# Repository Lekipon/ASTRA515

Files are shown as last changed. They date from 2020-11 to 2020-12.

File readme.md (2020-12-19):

## *ASTRA 515 : A Symmetrical 5x15 Ortholinear Keyboard*

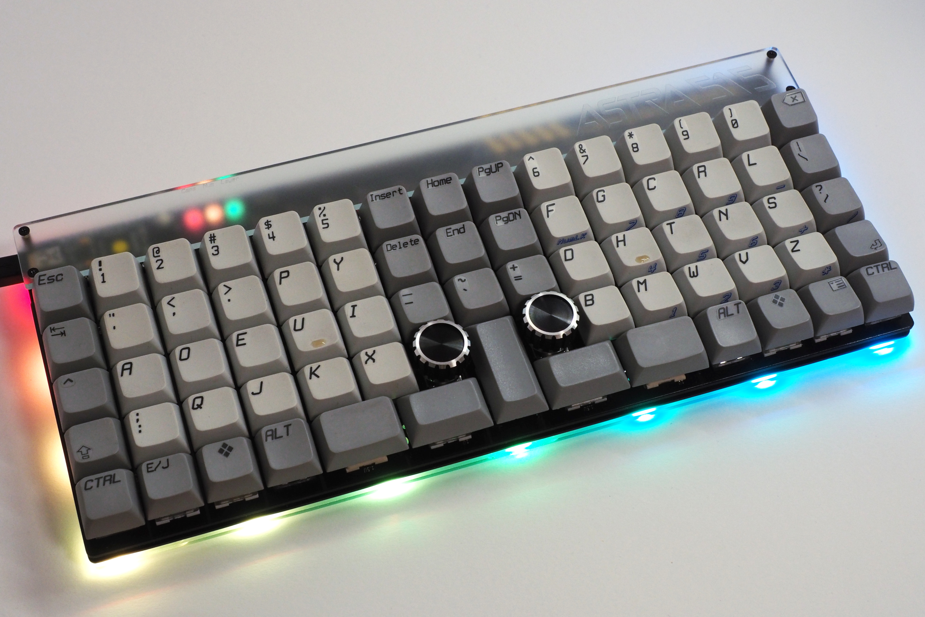
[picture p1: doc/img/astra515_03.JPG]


------

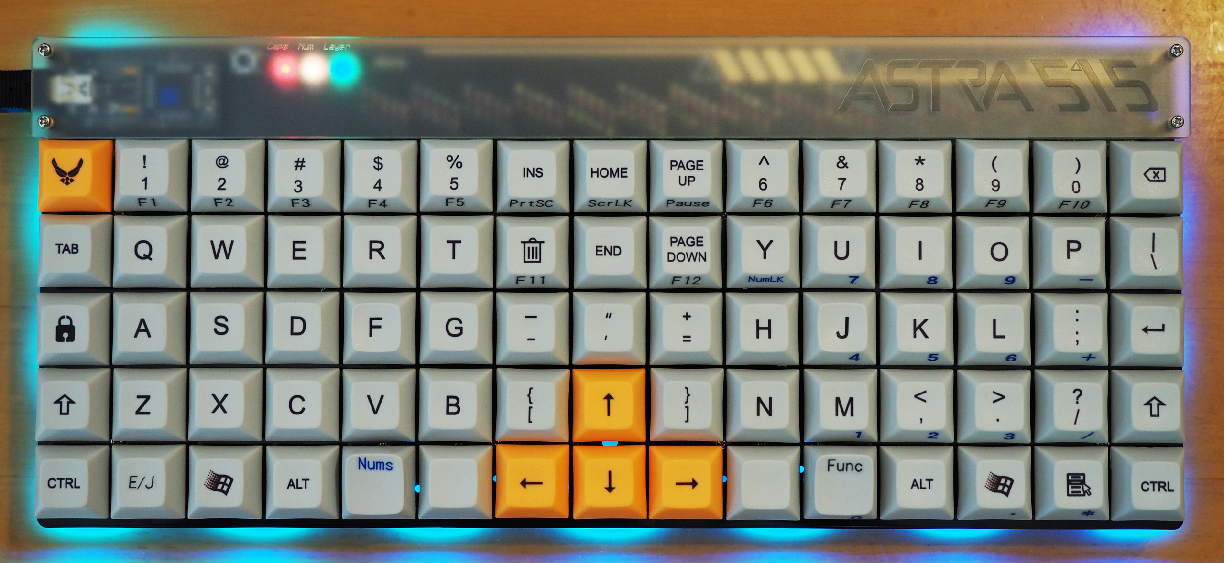
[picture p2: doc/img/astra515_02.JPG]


------

## **概要**

ASTRA 515は一体型の60％キーボードとほぼ同じサイズで5x15のオーソリニア（格子配列）となっている自作キーボードキットです。組立の難易度は決して高くないですが、キー数が多い故にハンダ付け箇所が多い点にご了承ください。

なお、ファームウェアは [QMK Firmware](https://github.com/qmk/qmk_firmware) を使用しています。

<br>

## 特徴

- ProMicro1個だけで可能な限り多くの実装をするためにDuplexMatrixの配線手法を利用。

- 左右の手のホームポジションの間隔を適度に離し、使用頻度の少ないキーを中央の区画に寄せた対称型オーソリニアレイアウト（全て1Uの構成にすれば片側寄せの非対称型のレイアウトも可能ですが...）。

- スイッチ付きロータリーエンコーダー（アルプスEC11/EC12互換）を2箇所に搭載可能。
- 好みに応じて親指周辺のキーを「1Ux3」または「1.5Ux2」の構成を選択可能（上の見本写真を参照）。また、中央下部のキーを縦の2U構成に変更することも可能（凸型配置の独立カーソルキーが不要な人向け、一般的には全て1Uの構成を推奨します）。

- RGBLED（WS2812B）による3連インジゲータの発光で「CapsLock」「NumLock」の状態を表示。また発光色によりレイヤーの状態を表示。

- RGBLEDのアンダーグロウに対応。なお、ハンダ付けの難易度がやや高いRGBLEDのみPCBに実装済。

- Kailhソケットにより大部分の区画がキースイッチの交換に対応（※中央下段の一部の区画を除く）。
- 標準添付のProMicroはUSBコネクタが「もげる」心配の無いMini-Bタイプを採用<br>（※別売となりますが普通のProMicroやElite-Cも使用出来ます）。

<br>

## キットに含まれている部品

1：PCB 1枚（RGBLEDを表面に3カ所、裏面に13カ所実装済）

2：スイッチマウントプレート

3：アクリルプレート3種（ボトムプレート用、トップカバー用、底上げ用、各1枚）

4：M2x8mmネジ（12本）

5：M2x5mmネジ（12本）

6：M2ワッシャー（8枚）

7：M2x12mmスタッドスペーサー（4本）

8：M2x4mmスペーサー（12本）

9：M2x3mmスペーサー（8本）

10：ゴム足（小3個、大3個）

11：Kailh PCBソケット（MX用・65個）

12：ダイオード（リードタイプ・75個）

13：ProMicro（Mini-Bタイプ・1個）および12ピンコンスルー（2本）

14：4ピンタクタイルスイッチ（リセットスイッチ用・1個）

<br>

## キットとは別に用意が必要な部品

- Cherry MX互換キースイッチ（73個）

- 1Uキーキャップ（73個）

- スイッチ付きロータリーエンコーダおよびツマミ（各2個）。なお、ロータリーエンコーダを使用しない場合はキースイッチと1Uキーキャップの必要数は各75個となります。

- USBケーブル（Mini-Bタイプ・1本）

<br>

## 必要な工具類

- ハンダごて（HAKKO FX600を推奨・別売コテ先はT18-C2かT18-D16がおすすめ）
- ハンダこて台
- 先が細いピンセット（ダイオードの足を曲げる際に必要）
- 普通のハンダ（スズ60％/鉛40％）およびハンダ吸い取り線
- フラックス（洗浄液もあるとなお良し）
- 精密ドライバーセット（100均のものでOK）
- マスキングテープ
- ニッパー
- プライヤー

<br>

## ビルドガイド

#### [**1：組立手順**](https://github.com/Lekipon/ASTRA515/blob/master/doc/buildguide.md)

#### [**2：デフォルトキーマップとQMKファームウェアについて**](https://github.com/Lekipon/ASTRA515/blob/master/doc/firmware.md)

#### [**3：ProMicroの換装について・他**](https://github.com/Lekipon/ASTRA515/blob/master/doc/promicro.md)

#### [**４：ロータリーエンコーダの選定について（沼）**](https://github.com/Lekipon/ASTRA515/blob/master/doc/re_numa.md)

<br>

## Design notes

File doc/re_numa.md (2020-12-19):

## ロータリーエンコーダの選定について（沼）

- ASTRA 515では当初からロータリーエンコーダを2カ所に搭載するように設計していますが、必ずしも付けなければならないという訳ではありません。最初は全てMX互換スイッチを実装して5x15Ortho配列のキーボードとして使い、配列に慣れてからロータリーエンコーダに換装するというのも有りだと思います。

- 作者自身は仕事で[XD75re](https://kprepublic.com/collections/xd75/products/xd75re-xd75am-xd75-xiudi-60-custom-keyboard-pcb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)を使用していて、そこから出てきた不満点を洗い出した上でASTRA515を設計したという経緯があるので、最初からロータリーエンコーダを付けていますが、５ピンのロータリーエンコーダは一度ハンダ付けすると外すのにコツが必要なので、初めての人はすぐに実装しない方がいいかも知れないとも考えてます（今更ながらですいません・・・）。

- ということで、ロータリーエンコーダをいくつか試してみて検証しましたので、以下にレビューを記載させていただきます。他の自作キーボードキットでロータリーエンコーダを使用する場合にも参考になるかと思います。

  <br>

**1）遊舎工房さんで取り扱っている[ロータリーエンコーダ＆ノブセット](https://yushakobo.jp/shop/pec12r-4222f-s0024/)**<br>

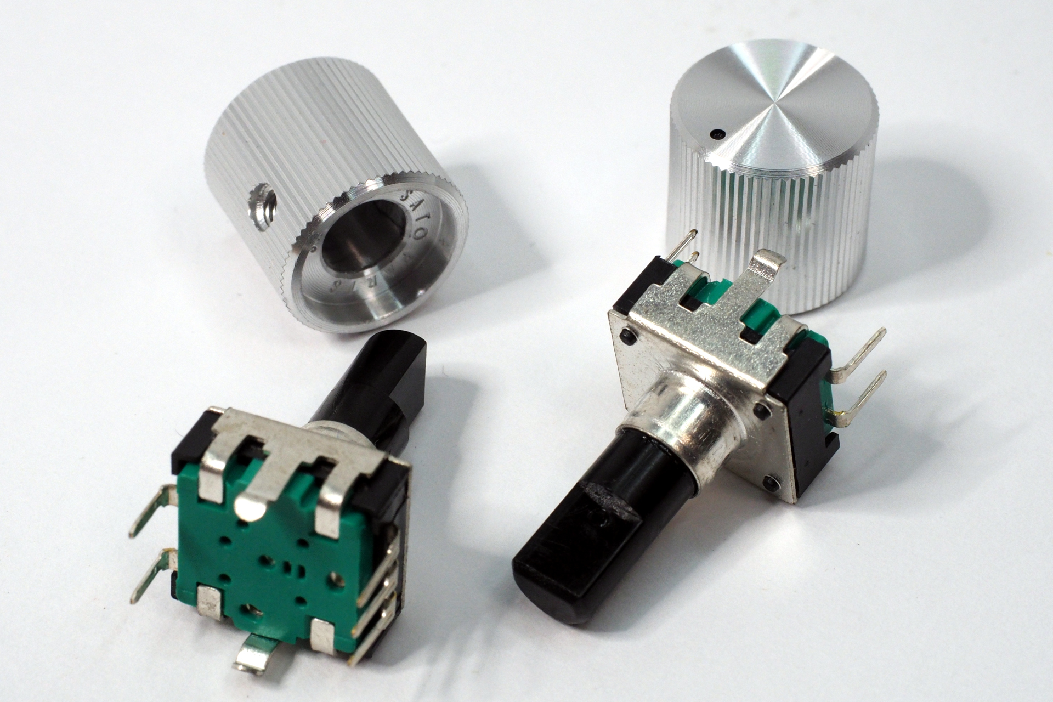
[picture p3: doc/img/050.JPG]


・Bourns社製の「PEC12R-4222F-S0024」とサトーパーツ社製の「K-29-6.1」アルミ削り出しノブのセットとなります。ノブだけでも単品で買うと350円とかする代物なので、なかなかのお買い得セットともいえます。

・PCB面からシャフト先端までの全高は22.5mmで、自作キーボードでの使用を考慮してやや短めのシャフトのとなっています。

・セットのノブは非常にシンプルな形状ながらも良好なグリップ感・・・特に側面と天面のエッジ部分の摩擦力が適正で、非常に実用的な選択だと思います。

・このセットではロータリーエンコーダが24パルス/24クリックのため、QMKファームウェアの「#define ENCODER_RESOLUTION」の値はデフォルト値の「4」の設定で使用します。

・実際に使った使用感ですが、プラスチックのシャフトながらも回した時の金属的なクリック感がなかなか心地よい感触です。あまりハードな使い方をしない前提なら、これで十分ではないかと思います。

・ただ、欲とは深いもので「親指一本でコロコロ回したいな～」とか「丈夫な金属シャフトのものを使いたい」といった欲が出てくると、以下のようにロータリーエンコーダ沼になってくるので十分に注意してください。

#### **2）アルプス EC11E18244A5**<br>

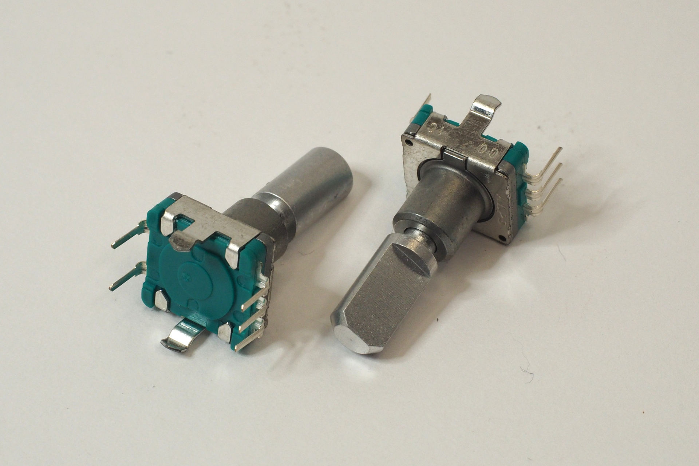
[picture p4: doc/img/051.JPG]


・PCB面からシャフト先端までの全高は24.5mm。プッシュスイッチは1.5mmと長いストロークで、柔らかいタッチが特長です。モノタロウやRSコンポーネンツで一個600円前後で売っています。

・18パルス/36クリックのため、QMKファームウェアの「#define ENCODER_RESOLUTION」の値は「2」の設定となります。具体的にはキーマップフォルダ内のconfig.hに当該セクションがありますので、設定値を「2」にしてファームウェアをビルドして使用します。

・EC11Eシリーズはこれがもっともシャフトが短い製品となりますので、このままでは自作キーボードで使用するには長すぎるという問題があります。ということで・・・<br>

#### **EC11Eのシャフトを斬る！**<br>

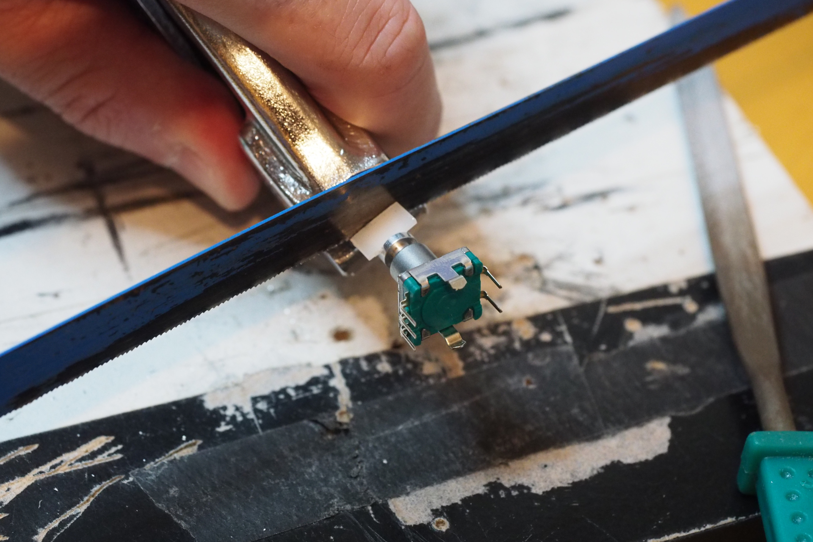
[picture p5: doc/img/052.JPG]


・金鋸を使用する際にはロータリーエンコーダの駆動部にダメージを与えないようにするために、必ずシャフト先端側をクランプしてカットします。

<br>

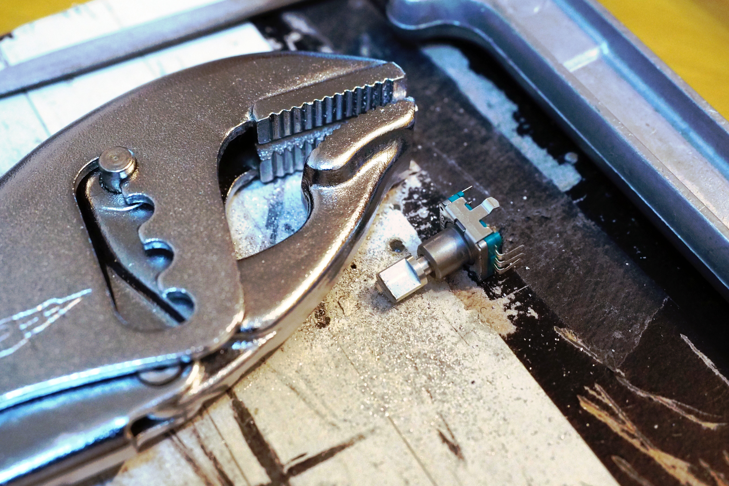
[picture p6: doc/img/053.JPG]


・5mmほどカットすれば、全高は約20mm弱。カット後はシャフトの先端のエッジ部分をヤスリで軽く面取りして仕上げます。自作キーボードでキーと隣接している状態ではこれくらいの低さが丁度いいくらいです。

・余談ですが、写真の工具は[スーパーツール社製のSG225](https://www.supertool.co.jp/products/products.php?eid=00084)。いわゆるバイスグリップ系の工具では世界的にも珍しい開口幅切り替え式が特長です。このシリーズの工具は個人的に何かと出番が多くて長年使っています。現在ではAmazonで2,200円で買えるので、一本持っておいても損はないと思います。

<br>

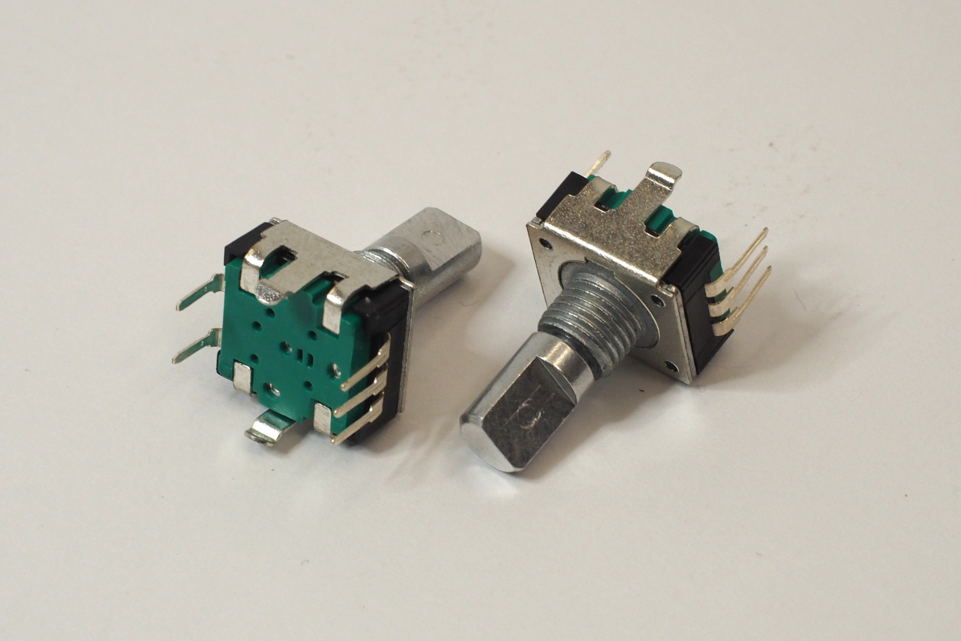
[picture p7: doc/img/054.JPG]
#### **3）Bourns PEC11R-4015F-S0024**<br>

・PCB面からシャフト先端までの全高は21.5mm（シャフト長が15mmでベース部分の高さが6.5mm）。プッシュスイッチは樹脂シャフトのPEC12Rシリーズ同様に0.5mmストロークの堅いタッチです。マルツオンライン等で一個250円前後で売っています。

・実は24パルス/24クリックの「PEC11R-4215F-S0024」と間違えてノンクリックの物を買ってしまい、これは失敗したなと思ったのですが・・・回転がとても軽くスムーズで指一本で簡単に回せるので逆に好都合でした。

・24パルス/ノンクリックのため、QMKファームウェアの「#define ENCODER_RESOLUTION」の値はクリック数を気にせずに自由に設定出来ます。例えば「2」に設定すると1回転で48回、「3」に設定すると1回転で32回、「4」に設定すると1回転で24回、といった出力回数となります。

・金属シャフトのPEC11Rシリーズではこれがもっともシャフトが短い製品となりますので、キーキャップの低さやノブの高さによっては、アルプスEC11E同様にシャフトを若干カットする必要が出てきます。<br>

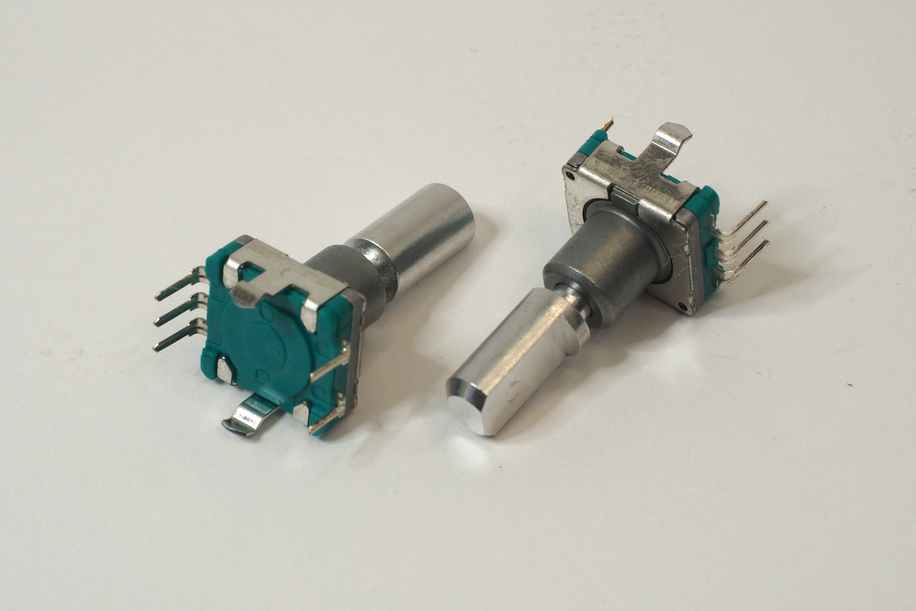
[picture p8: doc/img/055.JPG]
#### **4）アルプス EC11E1834403**<br>

・先に紹介した「EC11E18244A5」のノンクリック版。これもプッシュスイッチは1.5mmと長いストロークで、柔らかいタッチです。モノタロウやRSコンポーネンツで一個600円前後で売っています。

・18パルス/ノンクリックのため、QMKファームウェアの「#define ENCODER_RESOLUTION」の値はクリック数を気にせずに自由に設定出来ます。例えば「2」に設定すると1回転で36回、「3」に設定すると1回転で24回、「4」に設定すると1回転で18回、といった出力回数となります。

・こちらはノンクリックとはいえ、残念ながら中のグリスが堅いのか回転がかなり重いです。ただ、使い込むうちに次第に軽くなってくる傾向があるので。今後使い込んで馴染ませてみたいと思います。

<br>

## ノブの選択について（更なる沼）

- 上記でロータリーエンコーダについて数点のレビューをしましたが、ノブに関してはネジ止めで簡単に交換できる代わりに「実際に付けてみないと分からない」という要素がかなり発生します。奮発して買った高価なアルミ削り出しノブがイマイチで、安価な樹脂製ノブの方が良かったなんてことは茶飯事です。

- 一般に15mm径のノブなら周辺のキーの打鍵を妨げることはありませんが、18～19mm径クラスの大径ノブを使用すると隣接するキーが打ちづらくなるため、より低く装着する必要が出てきます。

- 現時点で下の写真のノブを試していますが、今後も徐々に増えていく可能性は十分あります。

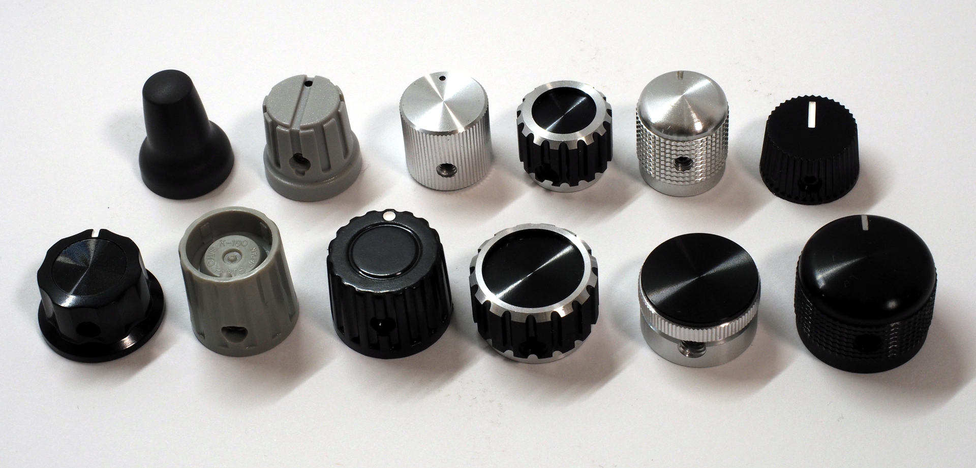
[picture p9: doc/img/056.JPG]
  

  <br>

  ・ここでは、実際に試したもののうち、いくつか写真付きでレビューしたいと思います。なお、ASTRA515に装着した見本写真では、PEC11R-4015F-S0024（全高21.5mm）とMX互換スイッチ、DSAキーキャップの組み合わせとなっています。

<br>

#### **1）サトーパーツ K-29-6.1**<br>

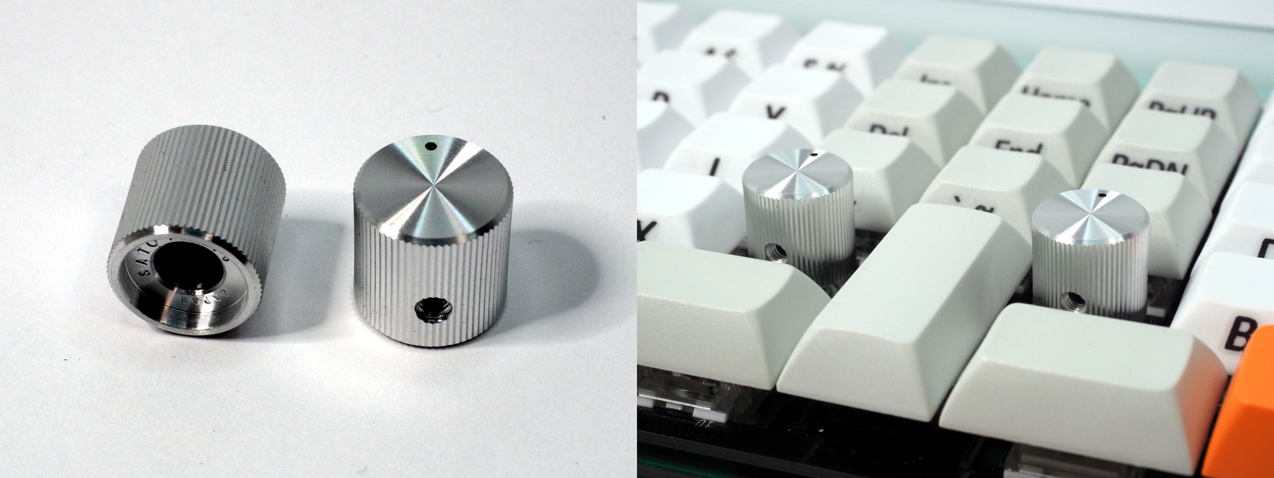
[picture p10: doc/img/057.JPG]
<br>

・詳細は[こちら](http://www.satoparts.co.jp/JPN/item/K/K-29-6.1/)。遊舎工房さんのロータリーエンコーダセットの添付品でもあります。

・見た目的な面白みはありませんが、エッジ部分の摩擦力が適正なため、指一本での回転操作にもある程度対応できます。

#### <br>**2）Linkman CP-CE15-5-S(6.1)W6**<br>

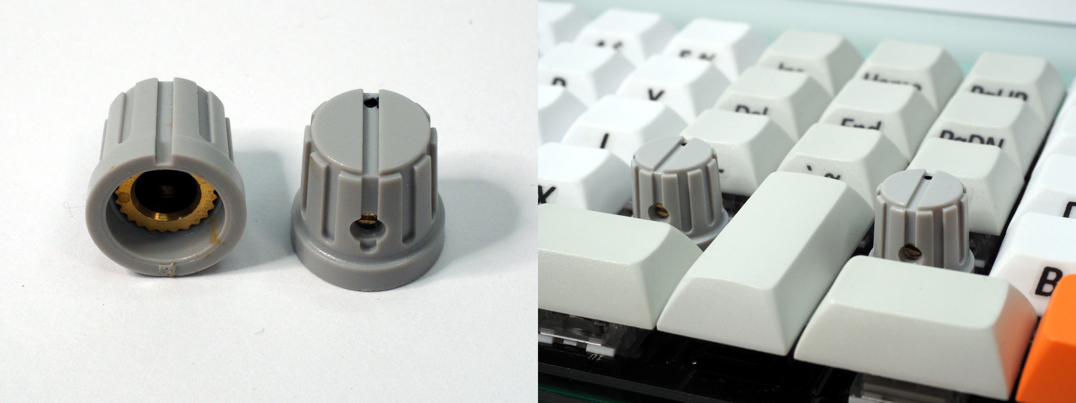
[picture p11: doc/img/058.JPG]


・詳細は[こちら](https://www.marutsu.co.jp/pc/i/837992/)。秋葉原の電子部品ショップでよく扱っている安価なノブです。グレーの他に黒色もあります。

・これも、エッジ部分の摩擦力が適正なところが良いと思います。また、グレー系のキーキャップに近い色で外観的にしっくりくるという良さもあります。

・取り付けの穴が結構深くて、プッシュスイッチと干渉しやすいので、あまり低く取り付けられないという欠点はあります。

<br>

#### **3）サトーパーツ K-4071**<br>

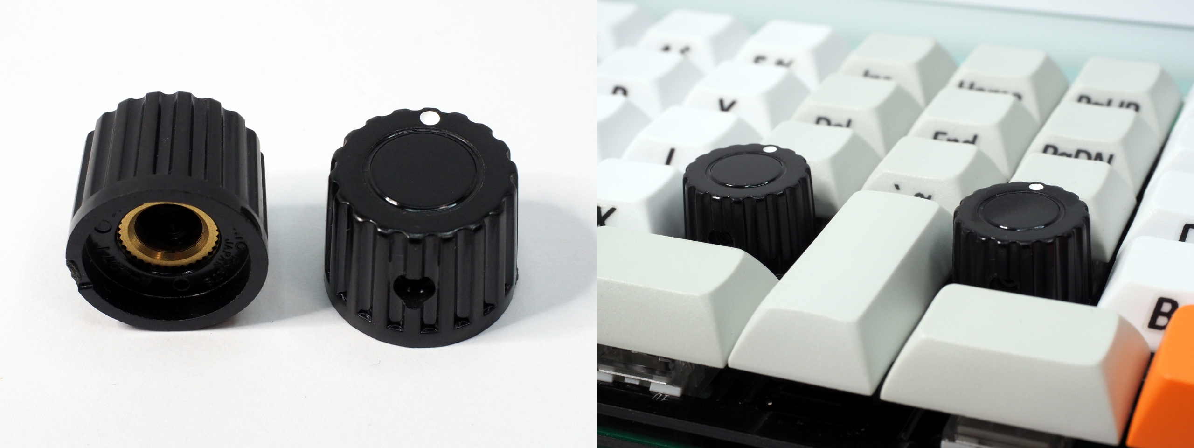
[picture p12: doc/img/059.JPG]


・詳細は[こちら](http://www.satoparts.co.jp/JPN/item/K/K-4071/)。マルツオンライン等で扱っています。

・大径でかつエッジ部分の摩擦力が適正、低く取り付け出来るためDSAのキーキャップとの相性も良いです。ただし、見た目が安っぽいのが一番の難点で色も黒しか有りません。実用性最優先の選択となります。

<br>

#### **4）サトーパーツ K-52-KE-3**<br>

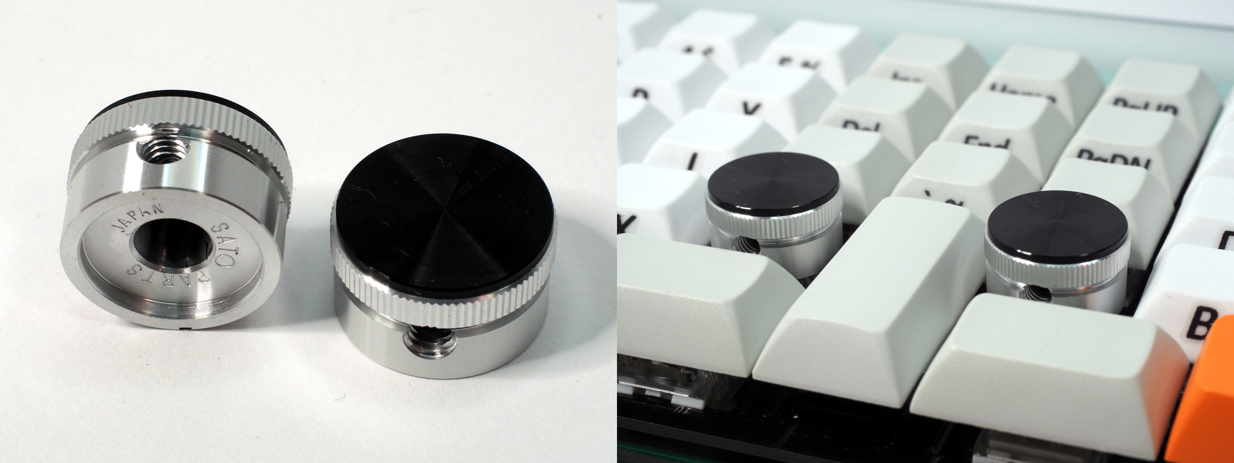
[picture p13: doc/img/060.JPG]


・詳細は[こちら](http://www.satoparts.co.jp/JPN/item/K/K-52-KE-3/)。マルツオンライン等で扱っています。

・大径ですが、エッジ部分の摩擦力があまり強くないです、低く取り付け出来ることと、外観が安っぽくないというのが良い点だと思います。

<br>

#### **5）サトーパーツ K-38（中）**<br>

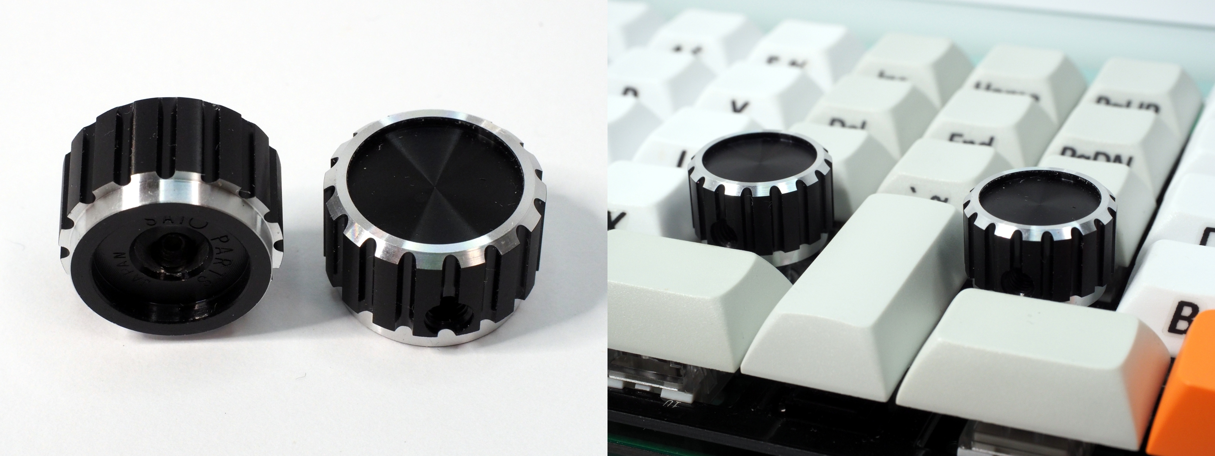
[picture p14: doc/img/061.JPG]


・詳細は[こちら](http://www.satoparts.co.jp/JPN/item/K/K-38/)。マルツオンライン等で扱っています。

・中サイズだと直径19mmでMXのキーピッチとマッチします。エッジ部分の摩擦力という点では最強ともいえます。ただし、断面図を見ての通り穴が浅いため低く取り付け出来ないという欠点があります。これはSAやMDAのような背の高いキーキャップと組み合わせて使うべきかと思います。

・削り出しのエッジが鋭いため、日々のエタノール消毒で肌荒れした指先には少々辛いという問題もあります。

<br>

<br>

（以上、必要に応じて随時書き足すかも）

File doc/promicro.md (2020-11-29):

# ProMicroの換装について

- ASTRA 515では一般的な自作キーボードキットと違い、標準添付のProMicroはやや大ぶりなMini-Bタイプのものとさせていただいています。理由は以下の通りとなります。
  - 基板のレイアウトが大柄な故にProMicroの設置場所に余裕があった。
  - HHKB等の市販キーボードでケーブル脱着式のキーボードでは、長年の間Mini-Bコネクタが標準だった（現在の市販キーボードではMini-BからType-Cコネクタに移行する過渡期）。
  - 通常のProMicroではMicroUSBコネクタが「もげる」問題に根本的な対策がされていない。
  - Mini-BタイプのProMicroも調達コストは通常のProMicroとほぼ同じ。<br><br>
- 上記の事情でMini-Bタイプを採用していますが、一般的な[ProMicro](https://yushakobo.jp/shop/promicro-spring-pinheader/)や[Elite-C](https://yushakobo.jp/shop/elite-c/)も使用可能なように設計してあります。MicroUSBコネクタは「もげる」問題があるので、換装の際はElite-Cを推奨しますが、MicroUSBケーブルを使いたい事情がある場合は、ProMicroのUSBコネクタをエポキシ接着剤等で補強して使用してください。
- なお、遊舎工房さんで取り扱っているProMicro（コンスルー付きで1,100円）について、少しだけ朗報があります。詳細は以下の比較写真をご覧いただければ分かりますが、USBコネクタがの実装が強化されています。

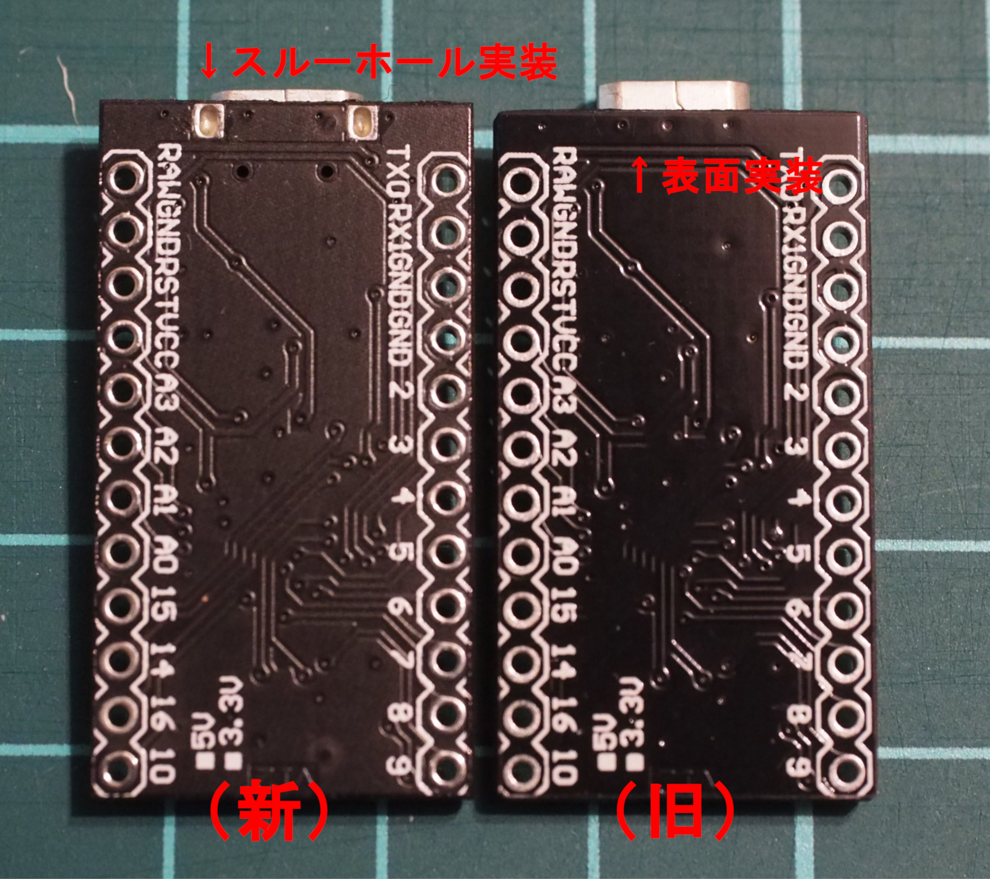
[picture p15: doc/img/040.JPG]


・USBコネクタの実装が表面実装からスルーホール実装に変更されています。また、基板の表面仕上げが艶ありから艶消しになっています。

<br>

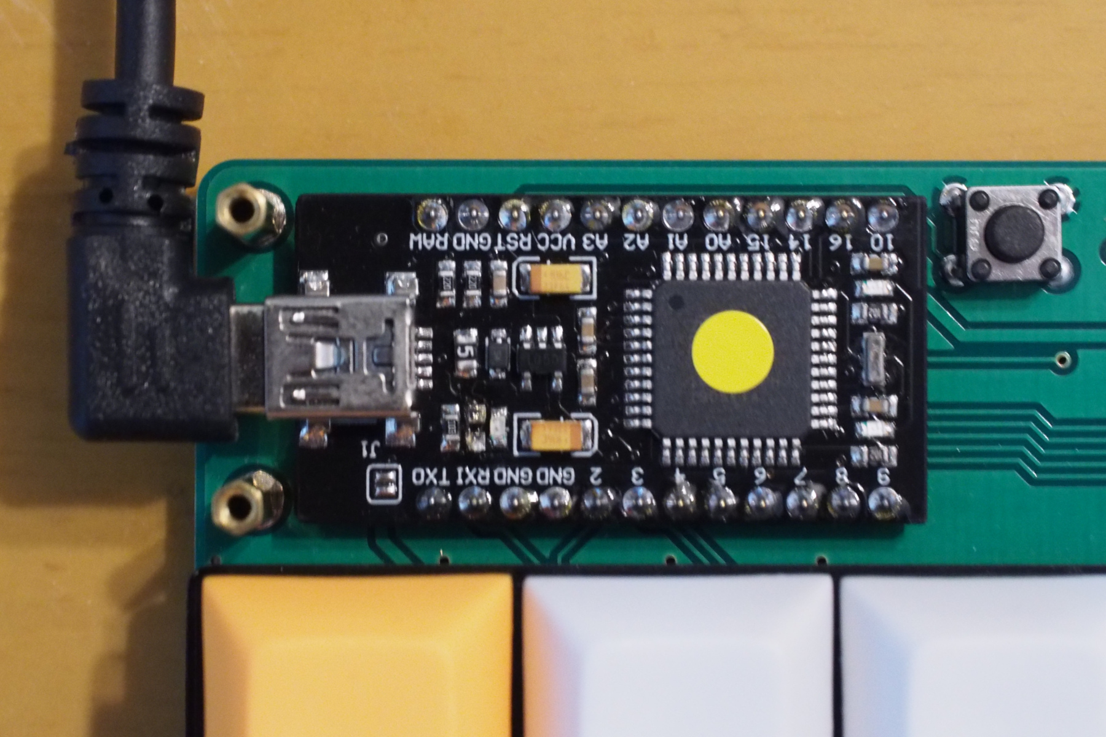
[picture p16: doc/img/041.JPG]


・スルーホール化されたとはいえ2カ所止めのままでは不安が残るので、結局は写真のようにエポキシ接着剤でコネクタ周辺を補強して使うことになります。強化されたこと自体よりも、補強の際に接着剤がコネクタ内部に流入しにくくなったというメリットの方が大きいかも知れません。

<br>

- 下の写真は標準添付のProMicroを取り付けた状態となります。

  

<br>

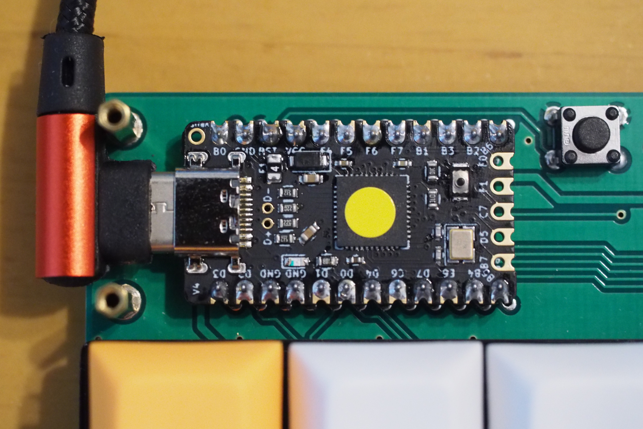
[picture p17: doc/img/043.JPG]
- これをElite-Cに換装した場合は以下の写真のようになります。

  ・ProMicroとの大きさの違いにより、Type-Cコネクタが奥まった位置になる点にご注意ください。

<br>

- この状態でL型のType-Cケーブルを使う場合は下の写真のように、コネクタの突き出し量が12mm以上あるものを使用してください。

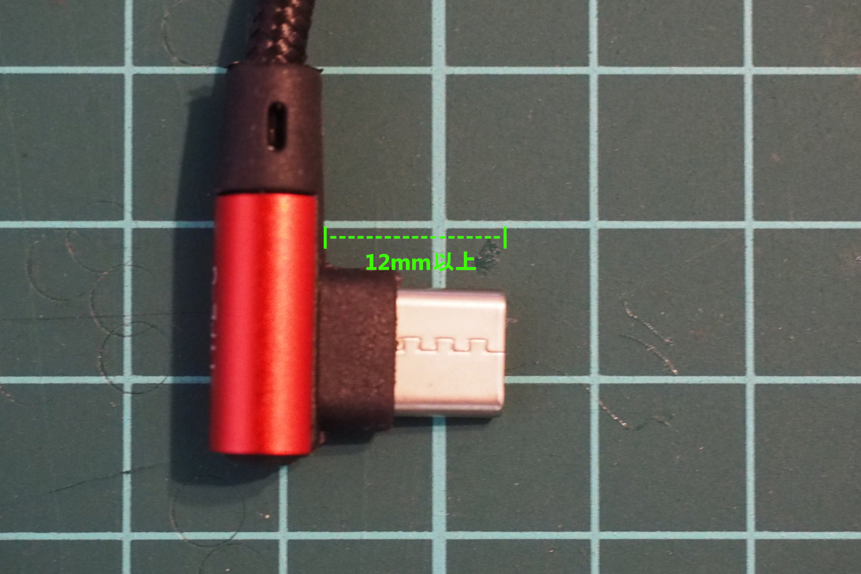
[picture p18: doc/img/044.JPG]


・余談ですが、写真のケーブルはダイソーで売ってるType-Cケーブルです。

<br>

<br>

## ProMicroの赤色LEDを消灯させる方法

- 標準添付のProMicroはVCCの赤色LEDの照度が強いため、マットのアクリルプレート越しでも目障りに感じる方もいるかと思います。
- その場合は、あくまで自己責任となりますが、LEDに繋がっている抵抗を除去してLEDを点灯しなくするという処置が可能です。これをするとスタンバイ消費電力も2mA程度の削減になります。

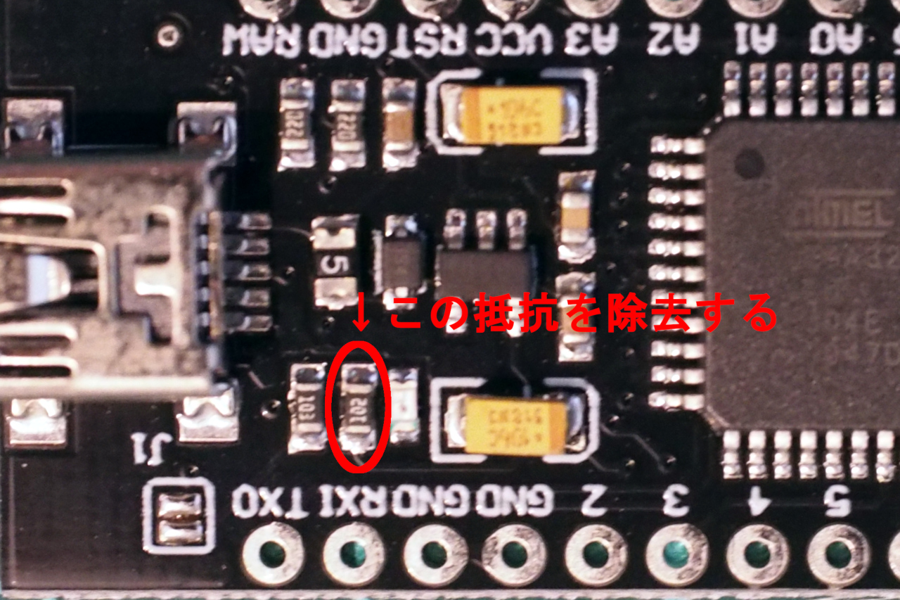
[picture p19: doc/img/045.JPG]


- 抵抗は表面実装部品なので、半田ゴテの二刀流が必要となります（30W程度あれば2本ともFX600である必要はありません）。抵抗の両側からコテ先で同時に加熱して横滑りさせるように力を掛ければ簡単に外れます。

- 間違っても隣接する部品にコテ先を当てないように注意しましょう。

  <br>

  <br>

  （以上）

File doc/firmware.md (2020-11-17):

# デフォルトキーマップとQMKファームウェアについて

## 1：デフォルトキーマップの説明

**レイヤー0　デフォルトレイヤー（ANSIモード）**

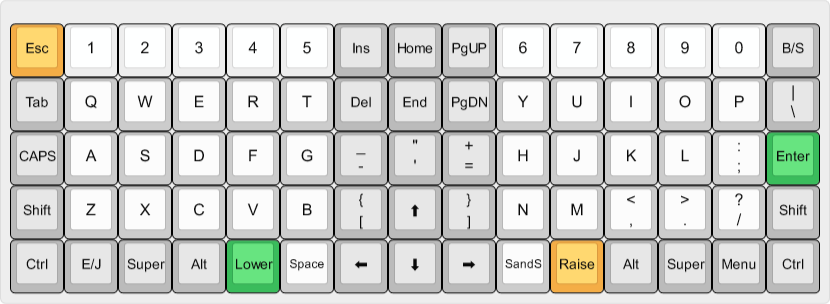
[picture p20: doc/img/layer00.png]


- デフォルトレイヤーはQWERTY配列をベースとした格子配列となっています。
- また、この状態ではレイヤーインジゲータのLEDは「暗い緑色」に発光します。
- 左右両方にスペースキーがありますが、右のスペースの「SandS」とは「タップでSpace、押しっぱなしだとShift」の兼用という設定になっています。右の親指でShiftを押せるようにしておくと何かと便利なため、この設定にしてあります。
- ロータリーエンコーダを付けた場合の設定は、左側のノブを回すとカーソルの上下移動、右側のノブを回すとカーソルの左右移動に割り当ててあります。プッシュボタンを押した時はそれぞれ" [ ”と” ] ”の記号を出す設定になっています（ロータリーエンコーダ無しの構成で組んだ場合に配慮のため）。
- このモードではPCのOS側は英語配列（104キーボード）の設定になっている必要があります。

<br>

**レイヤー1　JIS設定用レイヤー（JISモード）**

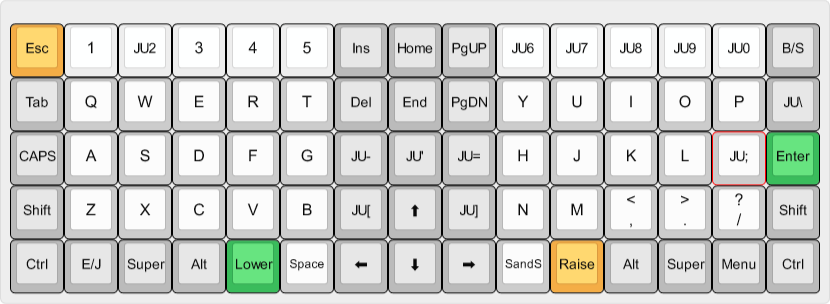
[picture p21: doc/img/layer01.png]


- このレイヤーはPCのOS側が日本語配列（109キーボード）の設定になっている場合に使うレイヤーです。
- また、この状態ではレイヤーインジゲータのLEDは「暗い青色」に発光します。
- 職場等でリモート接続先のPCだとOS側の設定が日本語配列になっている場合が普通なので、そのような場合に記号類の不整合を直すためにこのレイヤーに切り替えて使用しています。
- このモードに入る時は後述のADJUSTレイヤーにてJISモードに切り替えます。
- なお、このJISモードの実装については[koktohさんのjtu_custom_keycodes](https://github.com/koktoh/jtu_custom_keycodes)のコードを利用させていただいています。

<br>

**レイヤー2　RAISE（ファンクションキーレイヤー）**

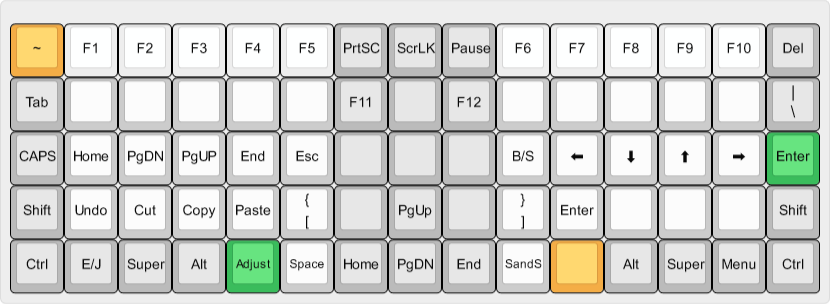
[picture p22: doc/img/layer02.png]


- このレイヤーは右手親指のRaiseキーを押している間だけ有効となります。
- また、この状態ではレイヤーインジゲータのLEDは「明るいオレンジ色」に発光します。
- 右手のホームポジションから指を動かすことなくカーソル移動が出来る設定になっていますが、PCゲームの「WASD」やVimの「HJKL」といったデファクトスタンダートなカーソル移動方法に慣れている人にとっては、かなり使いにくいかも知れません。
- 作者個人は過去にEmacsを使っていたこともあって「H」の位置に「B/S」そして「G」の位置に「Esc」を割り当てたいという事情もあってこのような「JKL;」の位置でカーソル移動させるレイアウトを採用させていただいています。
- また、Raiseを押しながら左手親指のLowerも押すと後述のADJUSTレイヤーに入ります。

<br>

**レイヤー3　LOWER（テンキー及び記号のレイヤー）**

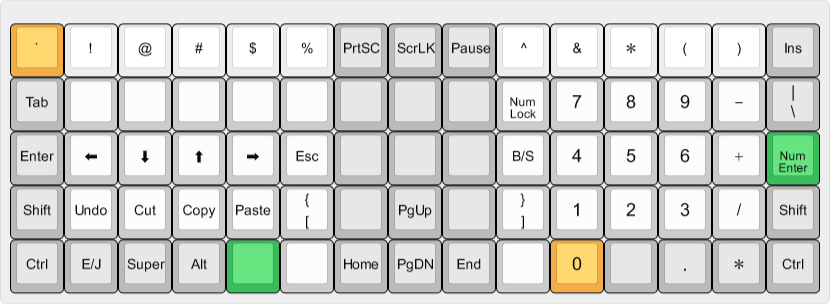
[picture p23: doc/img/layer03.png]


- このレイヤーは左手親指のLowerキーを押している間だけ有効となります。

- また、この状態ではレイヤーインジゲータのLEDは「明るい緑色」に発光します。

- 右手のホームポジションのままでテンキーの数字や記号が入力出来るようになっています。ただしNumLockがONになっていることが必要です。なお、NumLockの状態はNumのLEDが「明るい黄色」に発光しているかどうかで確認出来ます。

- 左手のホームポジションにカーソル移動とEnterを割り当てているのは、作者自身が右手で晩酌しながら左手でカーソル移動させることが多いためです。

- RAISE/LOWER共に" [ "と " ] "の記号を割り当てているのはロータリーエンコーダのプッシュスイッチが堅くて押しづらいことに対する配慮となります。

  <br>

**レイヤー4　ADJUST（各種設定用のレイヤー）**

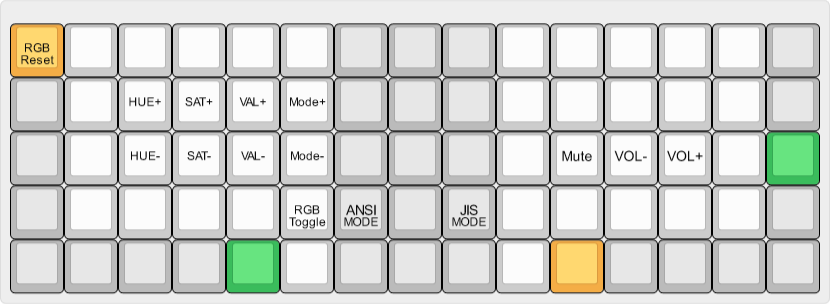
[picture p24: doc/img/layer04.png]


- このレイヤーは「Raiseキーを押しながらLowerキーを押している」間だけ有効となります。逆に「Lowerキーを押しながらRaiseキーを押し」てもテンキーの0が出力されるだけなのでご注意ください。
- また、この状態ではレイヤーインジゲータのLEDは「明るい水色」に発光します。
- アンダーグロウのRGBLEDの設定、PCの音量/ミュート設定、ANSI/JISモードの切り替えに使います。

- 例としてこのレイヤーで「JIS MODE」を押すとレイヤー1に切り替わります。JISモードからANSIモードに戻すときは、同様に「ANSI MODE」を押すとレイヤー0に切り替わります。

<br><br>

## **2：QMKファームウェアについて**

- QMK ToolboxをPCにインストールします。少し古い記事となりますが [サリチル酸さんのBlogの記事](https://salicylic-acid3.hatenablog.com/entry/qmk-toolbox)が大変分かりやすいです。

- QMKの[本家](https://github.com/qmk/qmk_firmware)には「ASTRA515」のコードはまだマージされていませんので、当面の間は[このフォークしたQMK](https://github.com/Lekipon/qmk_firmware)を使用してください。

- QMKのビルド環境の構築方法については、各自のOS環境に合わせて調べていただくようお願いします。特にWindowsでMSYS2環境内に構築する方法はトラブルが報告されているようなので、作者自身もあまり自信ありません（復習のために後日に[公式ドキュメント](https://docs.qmk.fm/#/ja/newbs_getting_started)を参照して実験してみる予定ですが）。

- 既にQMKファームウェアのビルド環境を構築をしている方は、ダウンロードしたqmk_firmware-master.zipを解凍して、出来上がった「qmk_firmware-master/」フォルダの中から「keyboards/lekipon」以下の中身をご自身のビルド環境にコピーしても大丈夫だと思います

  （lekiponフォルダには作者が他に開発したキーボードのファームウェアも一緒に入っています）。

  <br>

- ビルドする際にはコマンドライン上でQMKビルド環境のルートフォルダに入って、以下のコマンドでコンパイルします。

```
make lekipon/astra515:default
```

- これでQMKビルド環境のルートフォルダに「lekipon_astra515_default.hex」というファイルが生成されます。このファイルをQMK ToolboxでProMicroに書き込みます。

<br>

- コマンドライン上でそのままProMicroに直接書き込む時は以下のコマンドとなります。

```
make lekipon/astra515:default:flash
```

- Elite-Cを使用する場合は、ProMicroとブートローダーが違うため以下のコマンドとなります。

```
make lekipon/astra515:default:dfu
```

<br>

- ご自身でキーマップをカスタマイズする場合は「keyboards/lekipon/astra515/keymaps/」内で「default」フォルダを別の名前にコピーして「keymap.c」をテキストエディタで編集してください。

- なお、動作確認の為にデフォルトの[HEXファイル](https://raw.githubusercontent.com/Lekipon/ASTRA515/master/hex/lekipon_astra515_default.hex)を用意していますが、標準添付のProMicroに書込済のものと同様になります。

<br><br><br>

（以下、必要に応じて随時追記するかも...）

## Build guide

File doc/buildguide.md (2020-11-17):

# ASTRA515 組立手順

この度は「ASTRA 515」をお買い上げいただきまして誠にありがとうございます。
このキーボードキットは<u>5行x15列の格子配列で設計されたキーボード</u>となります。

ファームウェアについては[QMK Firmware](https://github.com/qmk/qmk_firmware)を採用しており、多少のスキルや慣れは必要ですがユーザー自身で自由に各キーの割り当てを変更することが出来ます。

なお、このキットは初歩的なハンダ付けを含む組立が必要です。

ハンダ付けの難易度が比較的高いRGBLEDに関しては予め手作業で実装した状態で梱包しておりますが、比較的キー数が多く実装部品も多いため、正直言って「簡単だけど面倒くさい」キットとなっている点にはご了承ください。また、当方では「完成品が欲しい」「組立作業を代行して欲しい」といったお問い合わせに応じることは出来ません。

自作キーボードのキットですので出来上がった完成品を使うことで得られる結果だけでなく、それを作る過程も含めて楽しんでいただけたら幸いです。

<br>

<br>

## 1：キット添付品の確認

**1）PCBとスイッチマウントプレート**

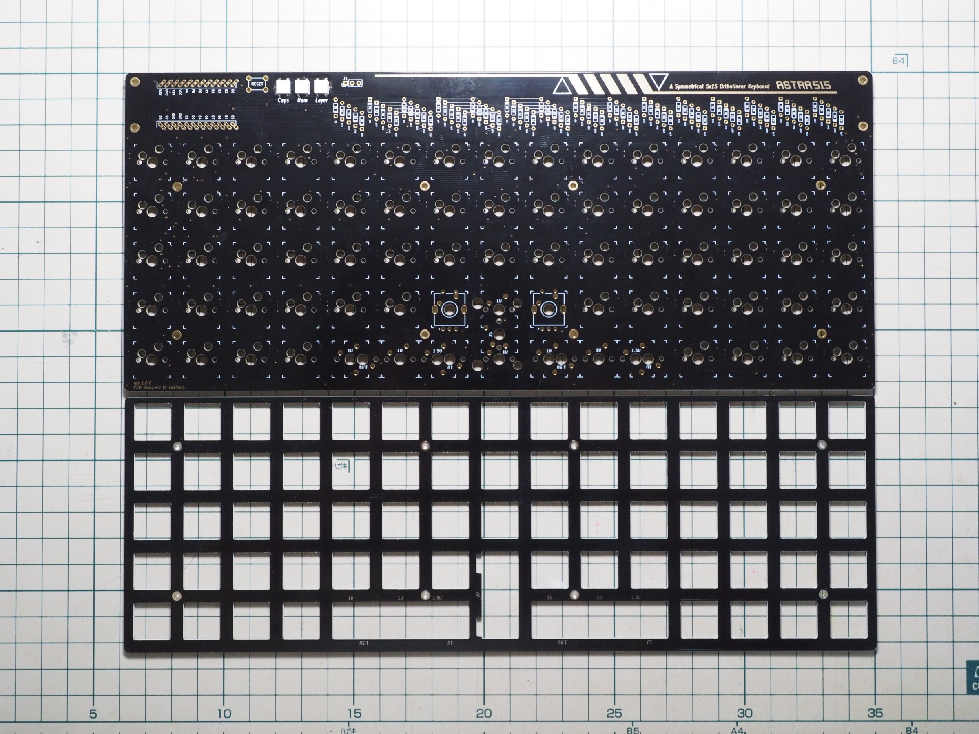
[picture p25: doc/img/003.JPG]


- PCBにはWS2812Bが表面に3カ所、裏面に13カ所実装されています。

<br>

**2）アクリルプレート（３種類）**

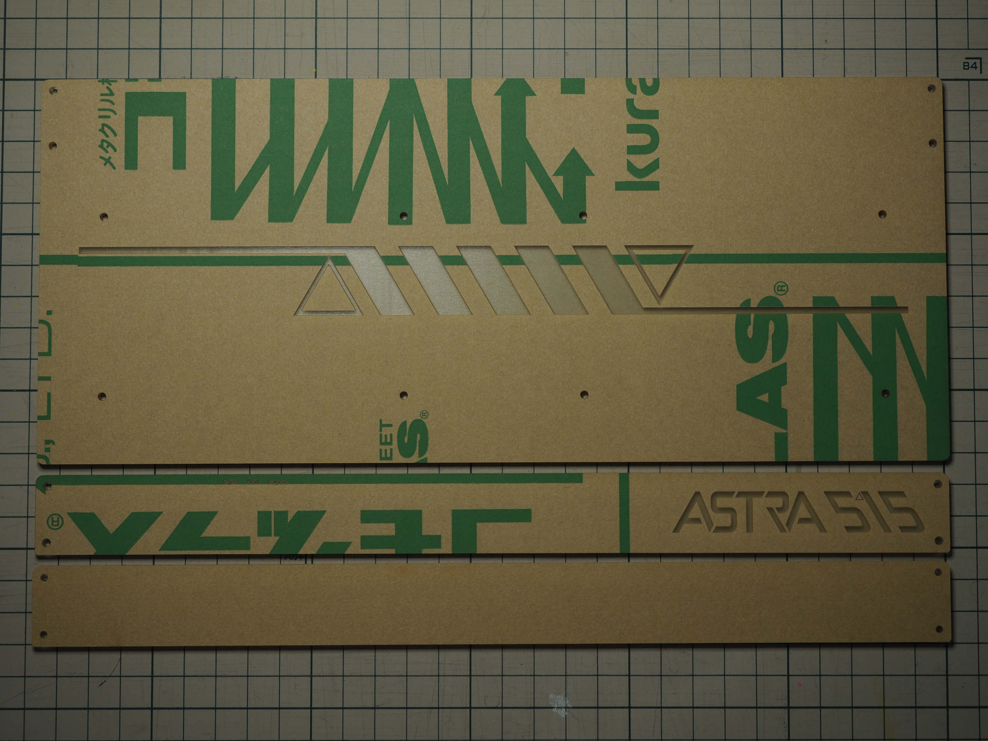
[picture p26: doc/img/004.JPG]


- 上から順にボトムプレート用、トップカバー用、底上げ用となります。

<br>

**3）ネジ・スペーサー類**

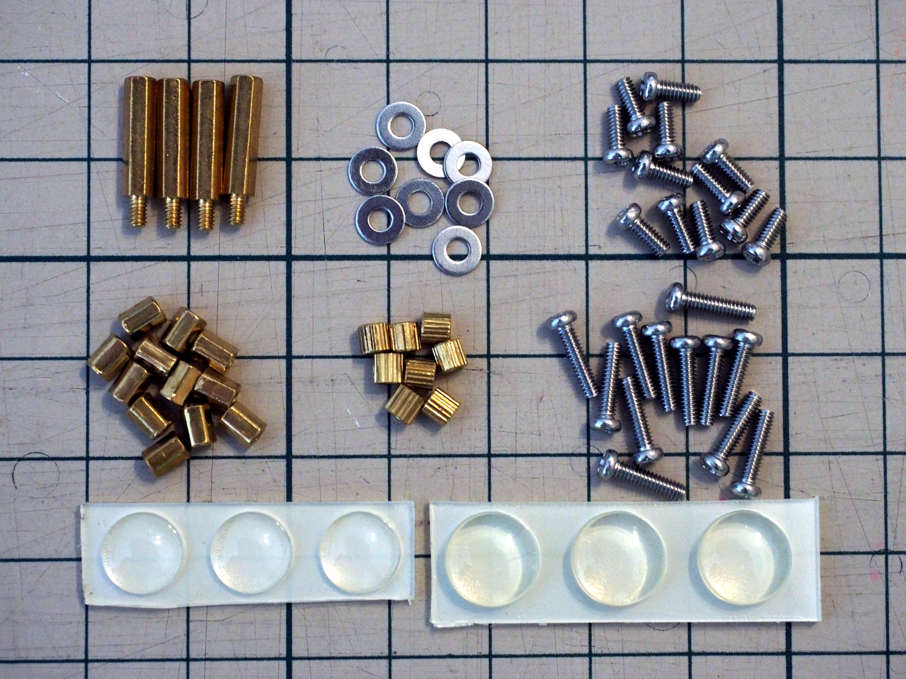
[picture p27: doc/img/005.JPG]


①M2x12mmネジ：12本

②M2x5mmネジ：12本

③M2ワッシャー：8枚

④M2x3mmスペーサー：8本

⑤M2x4mmスペーサー：12本

⑥M2x12mmスペーサー：4本

⑦ゴム足：大3個、小3個

<br>

**4）Kailh PCBソケット（MXスイッチ用65個）**

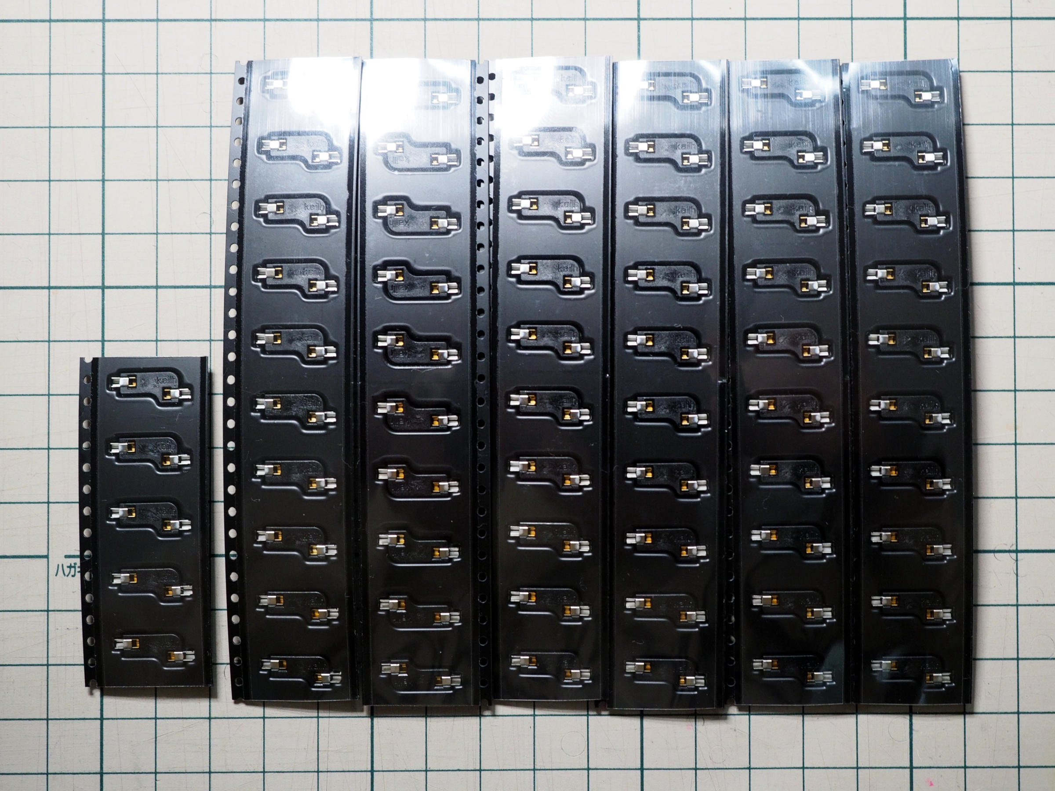
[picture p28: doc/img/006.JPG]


<br>

**5）ダイオード（75本）**

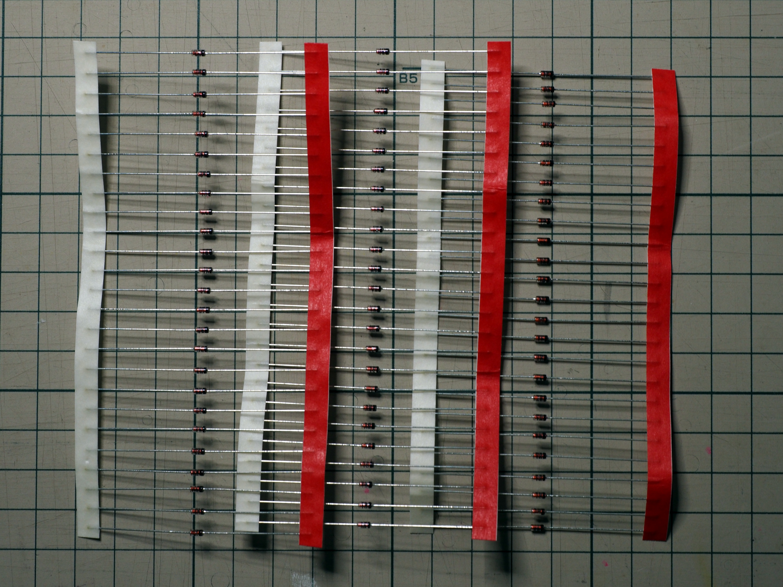
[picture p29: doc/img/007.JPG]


<br>

**6）ProMicro（Mini-Bタイプ）、コンスルー、タクタイルスイッチ**

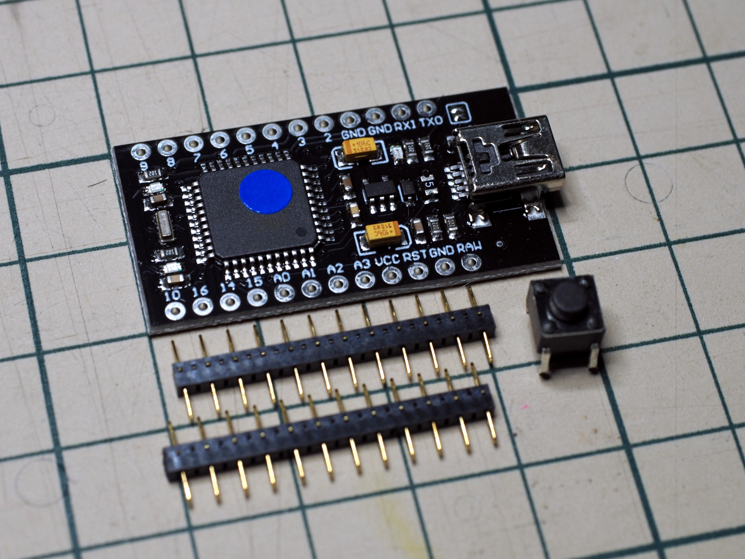
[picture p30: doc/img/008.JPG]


- ProMicroにはデフォルトファームウェアを書込み済となっています。基板にバリが残っているので、側面に軽く紙やすりを掛けた上でゼブラの黒マッキー等で側面を黒塗りしておくことをお勧めします。

<br>

<br>

## **2：PCBへのダイオードの取り付け**

<br>

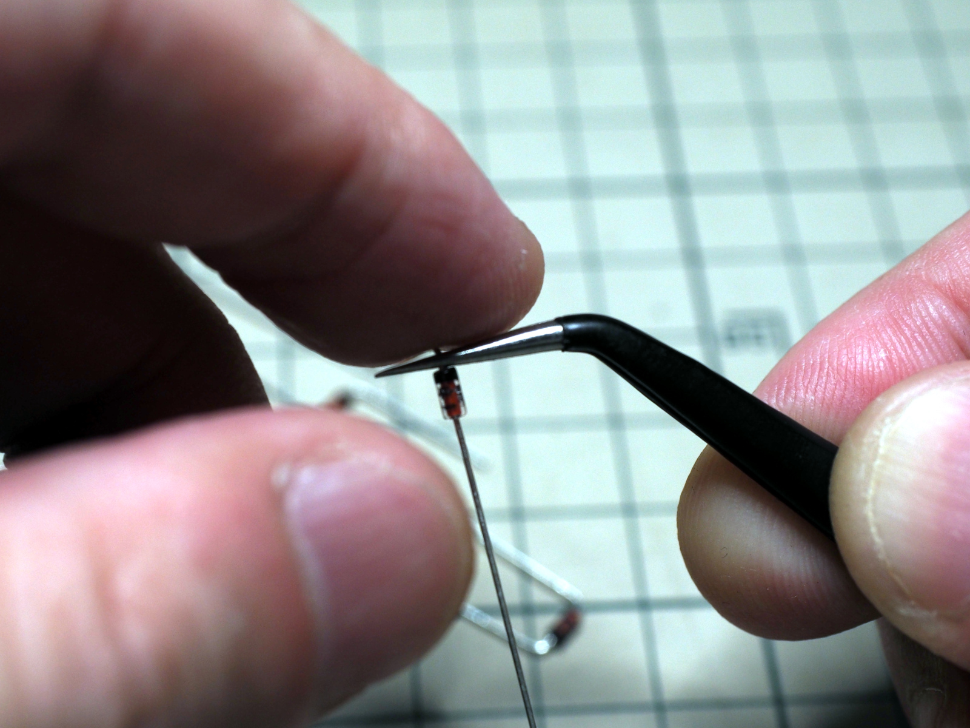
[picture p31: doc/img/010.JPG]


- 写真のように先が細いピンセットでダイオードの根元をつまんで足を直角に曲げていきます。なお、PCB側のダイオード用の穴は6.35mmの間隔で設計していますので、その穴にマッチするように曲げていってください。

<br>

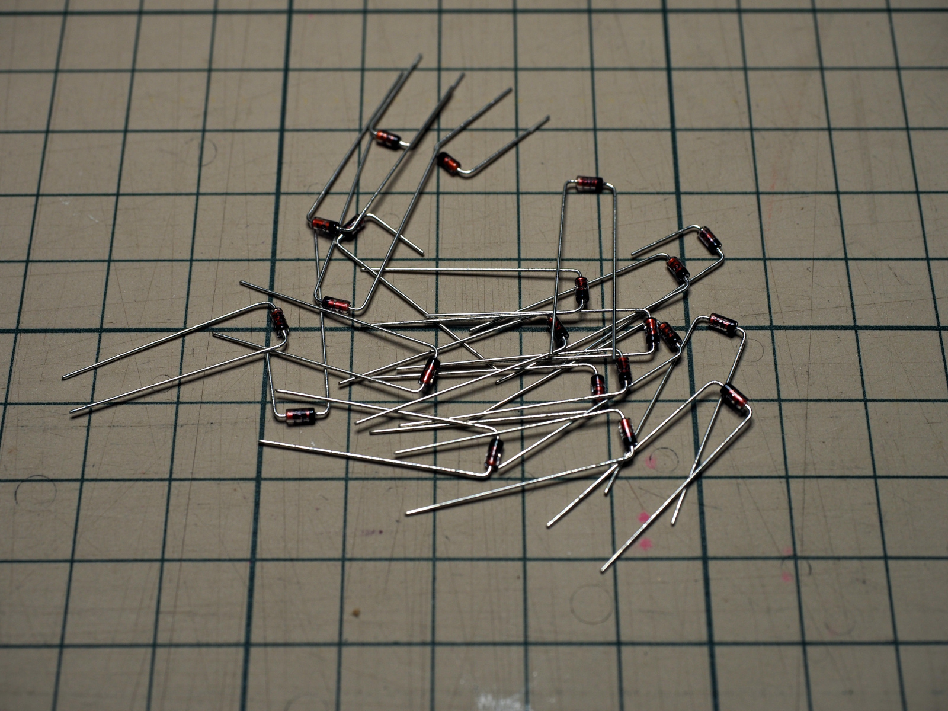
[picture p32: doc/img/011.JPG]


- このように両方の足を曲げたダイオードを全部で75本作っていきます。正直「面倒くさい」作業ですが、一つ一つのダイオードが全て役割を持っているということを感じていただけたら幸いです。

  <br>

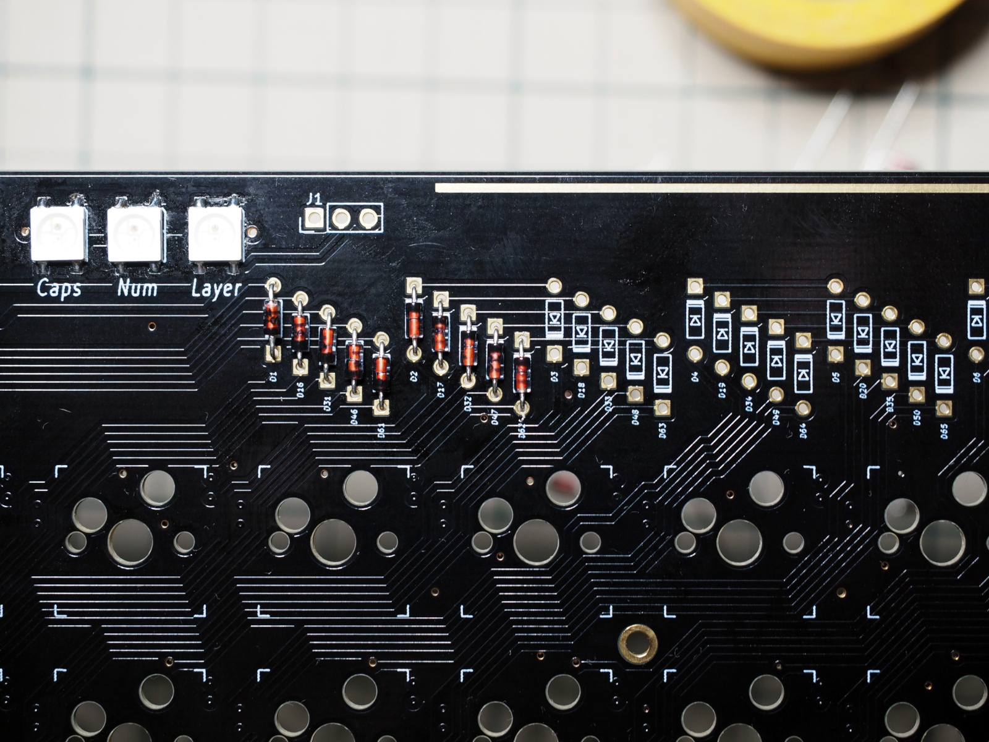
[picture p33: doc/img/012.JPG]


- PCBの表面からダイオードを差し込んで行きます。なお「ASTRA 515」ではDuplexMatrixの配線をしている関係上、写真のように5個一組で交互に実装方向が反転しているのが特徴です。PCB表面のシルク印刷でも実装方向を明示していますが、原則として「四角い穴のある側に黒い印がくるように」と覚えていただければ結構です。

- 試しに方向の間違いがなく10本差し込んでみたら、表面からマスキングテープを貼ってダイオードを固定してみましょう。

<br>

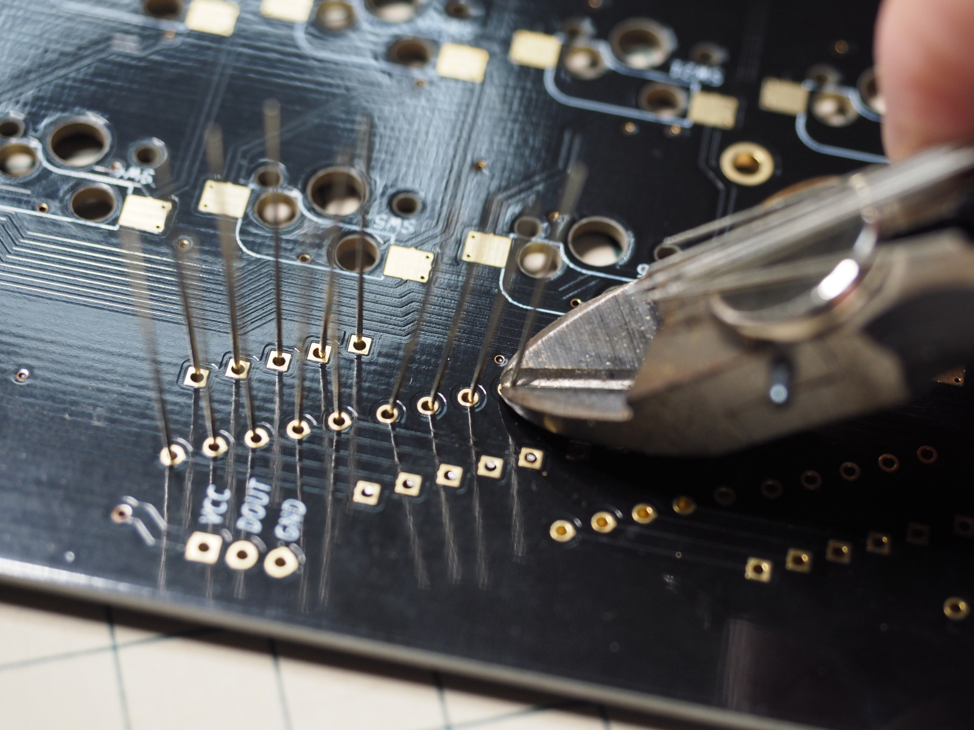
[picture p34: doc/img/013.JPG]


- PCBを裏返してニッパーでダイオードの足を切って行きます。切る長さですが、気持ち的には「ツライチ」にする感じでいいと思います。

- なお写真ではニッパーに100均の強力マグネットを貼り付けているため、切った足は自動的にマグネットに吸着されるようになっています。

<br>

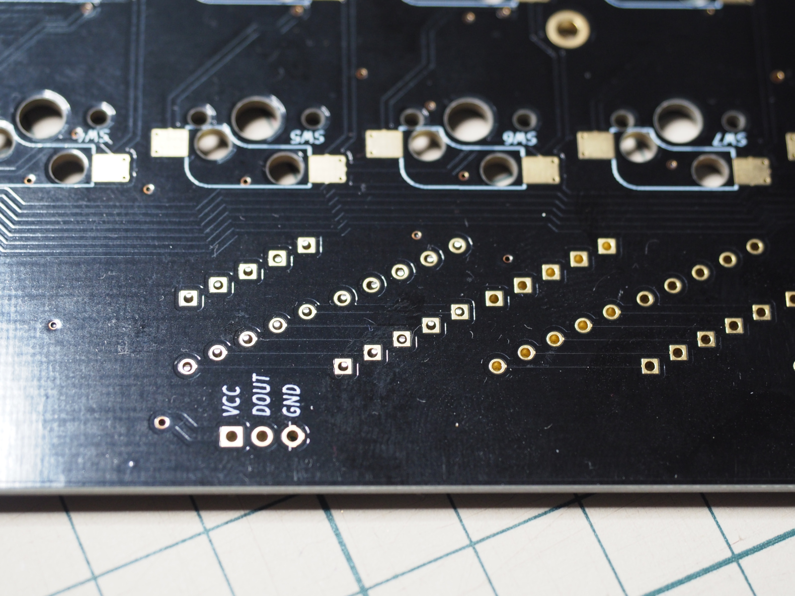
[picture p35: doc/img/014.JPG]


- 「ツライチ」のつもりで切っても僅かに表面に足が出た状態になります。個人的にはこれくらいが好みです。

<br>

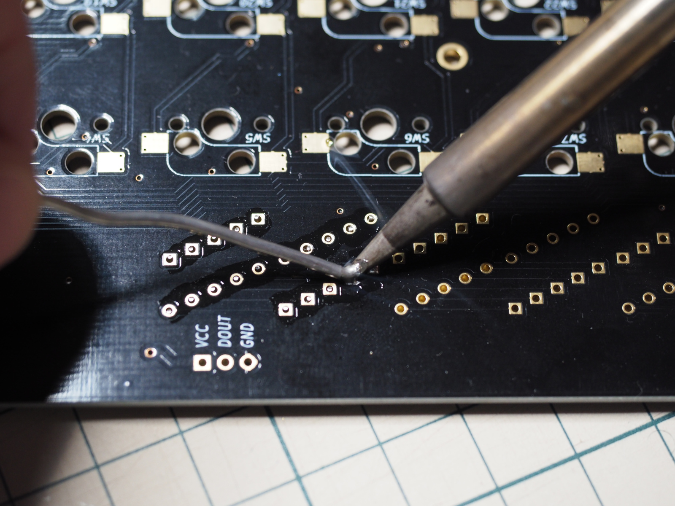
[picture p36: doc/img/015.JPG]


- スルーホール部品のハンダ付けでは必須ではないですが、軽くフラックスを塗布した上でハンダ付けを行います。なお、FX600での温度設定は終始320℃の設定で支障ありません。

<br>

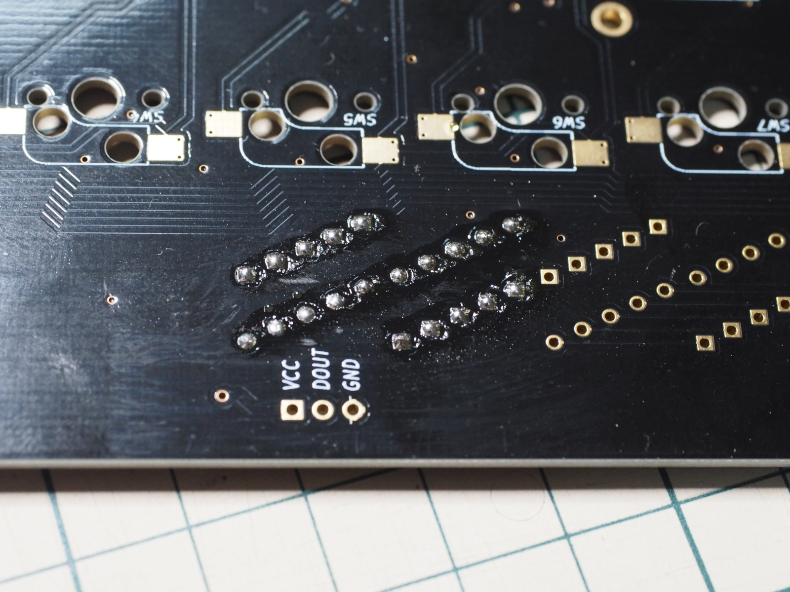
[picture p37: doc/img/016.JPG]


- これで最初のダイオード10個が実装されました。この後も10個づつ慎重に実装をしていくといいでしょう。なお、実装後のフラックス汚れは一段落ついた後でフラックス洗浄液で落とせば綺麗になります。

<br>

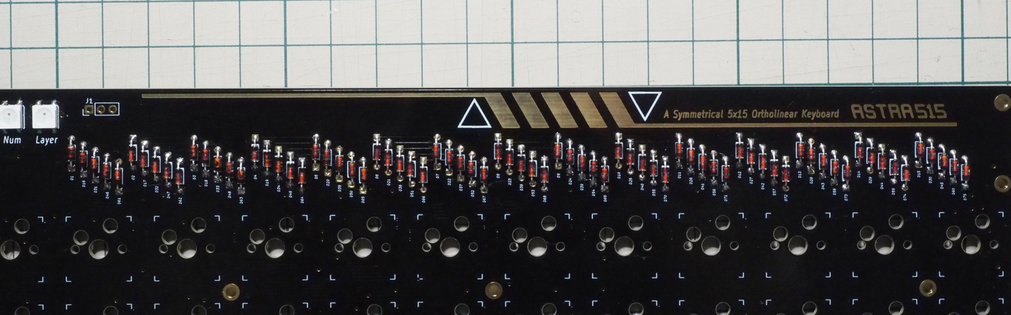
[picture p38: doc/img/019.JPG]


- 全てのダイオードの実装が完了すると写真のようになります。

- ここまでの工程で数時間は掛かっているはずなので、一旦休憩を入れた方がいいと思います。

<br>

<br>

## **3：PCBへのKailhソケットの取り付け**

<br>

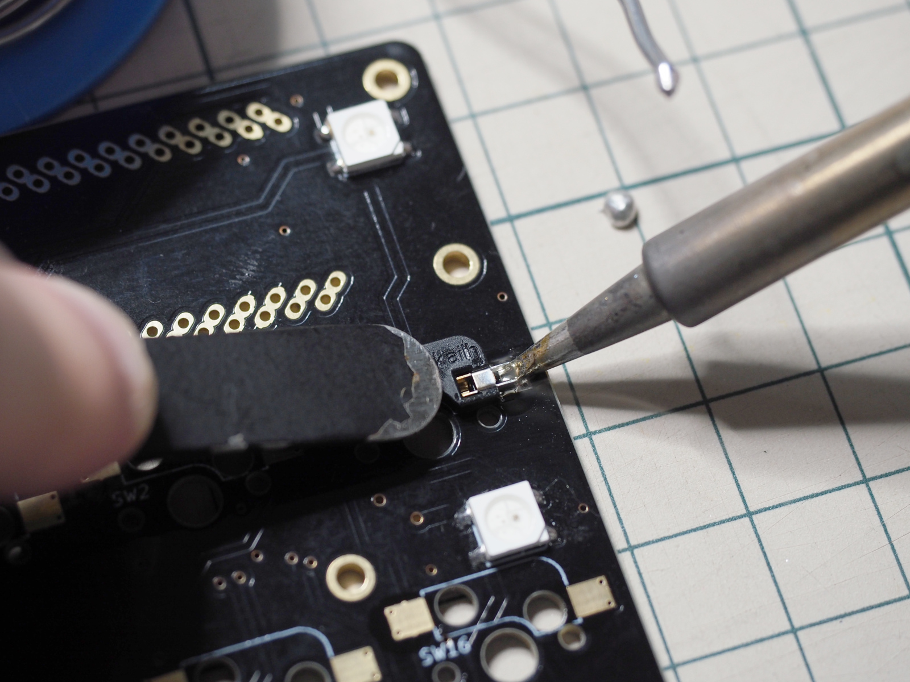
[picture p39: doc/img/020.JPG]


- PCBを裏返しにしてKailhソケットをハンダ付けしていきます。難易度の低い部品ですが、表面実装のためパッドには必ずフラックスを塗布するようにしてください。

- この工程のソケット部品はFX600に標準添付のB型コテ先だと熱を伝えにくいのでC2やD16のように平面とエッジのあるコテ先の使用をお勧めします。コテ先に予めハンダを盛った状態でパッドと端子を加熱すると「ジョワっ」という音と共にハンダがスムーズに流れ込んで行きます。

- 片側をハンダ付けしたら、基板を180度反転させて反対側からも同様にハンダ付けします。

- ハンダの消費量が多く煙が沢山出る作業なので、部屋の換気をしておいた方が良いと思います。

<br>

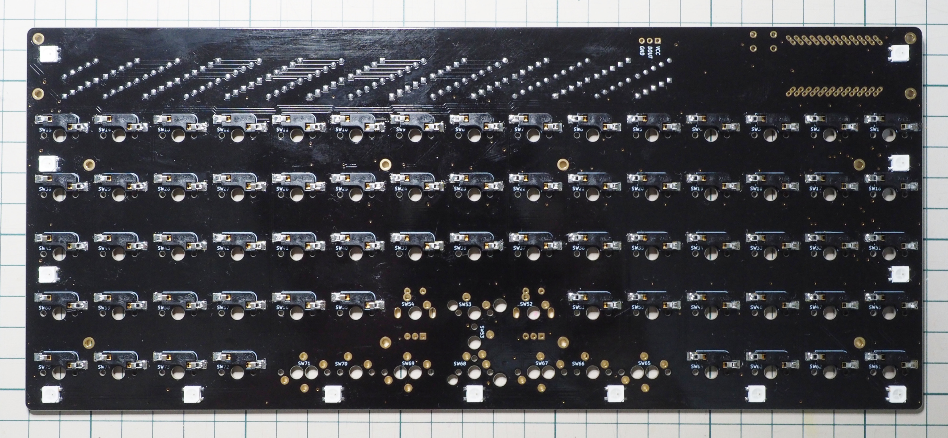
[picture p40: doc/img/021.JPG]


- 65個全てのソケットを実装すると写真のようなります。なお、中央下部のソケットの無い区画はロータリーエンコーダの実装やキーサイズ選択制の都合によりソケット非対応とさせていただいてます。

<br>

<br>

## **4：ProMicroの取り付け**

<br>

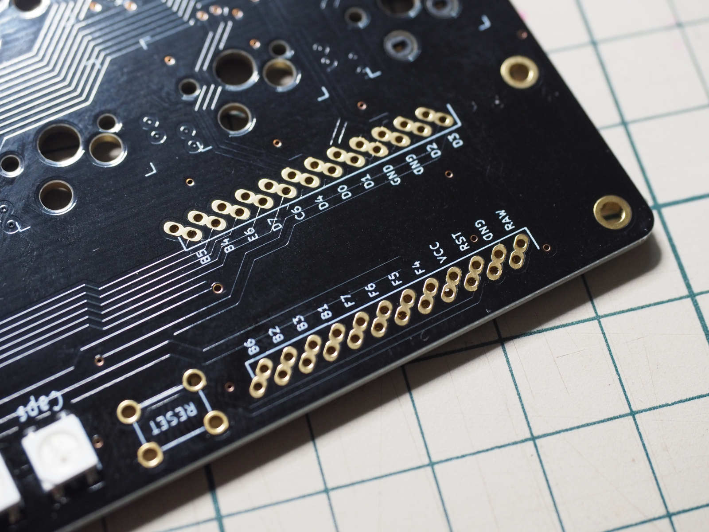
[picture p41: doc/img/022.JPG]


- PCBのProMicro取り付け箇所は写真のようになっています。大きめなMini-BタイプのProMicro（700mil幅）と通常サイズのProMicro（600mil幅）の両方に対応しているため2種類の幅の列に穴が用意されています。

- なお、添付品のMini-BタイプのProMicroでは外側の列の穴を使用します。

<br>

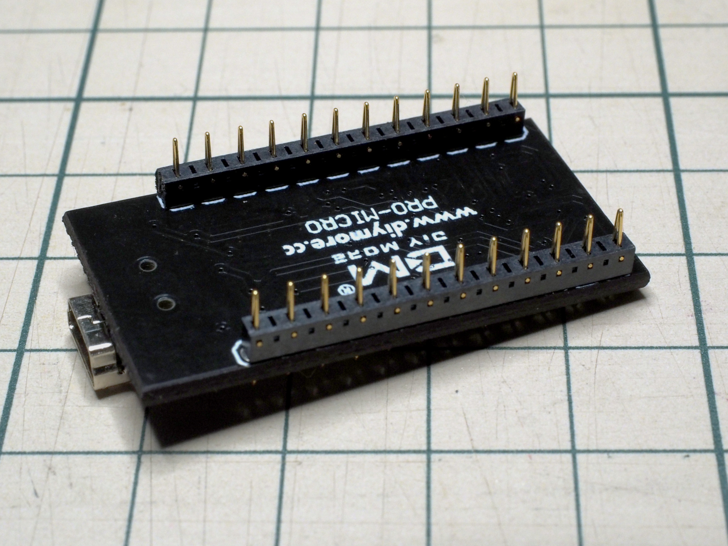
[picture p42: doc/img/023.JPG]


- ProMicroにコンスルーを差し込みます。コンスルーの取り付け方向には決まりがありますので、写真を参考にして間違えないようにしましょう。

<br>

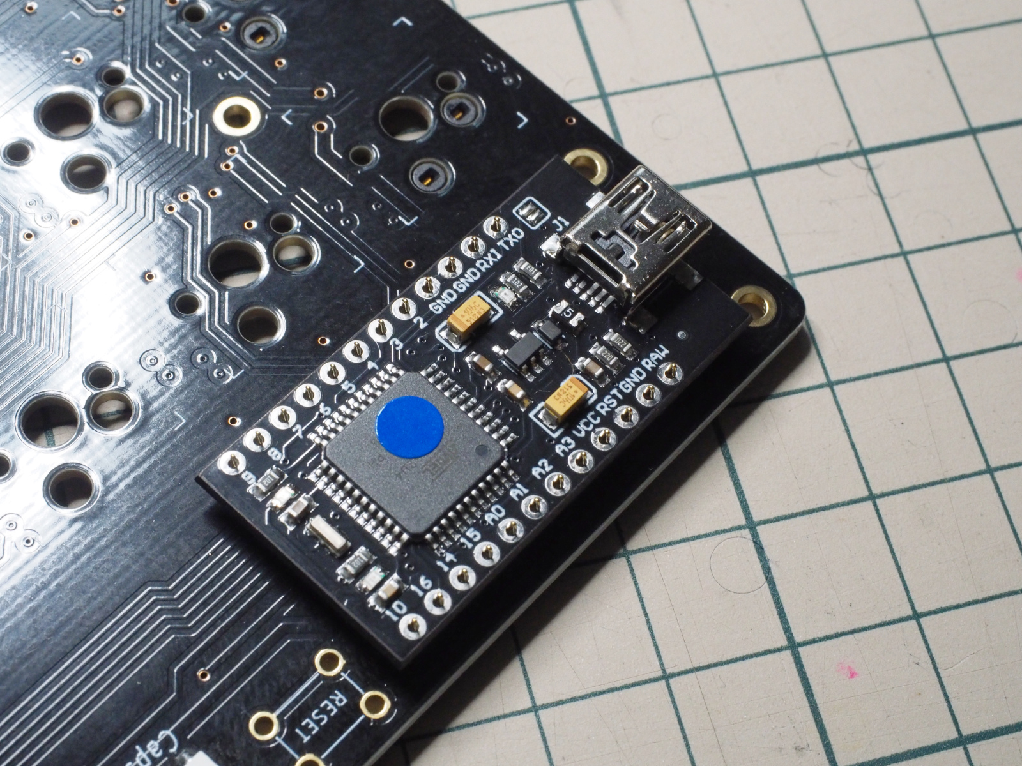
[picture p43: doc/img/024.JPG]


- コンスルーを装着した状態でProMicroをPCBの穴に差し込みます。先に説明したとおり、Mini-BタイプのProMicroは幅が広いので外側の列の穴に差し込むようにします。

<br>

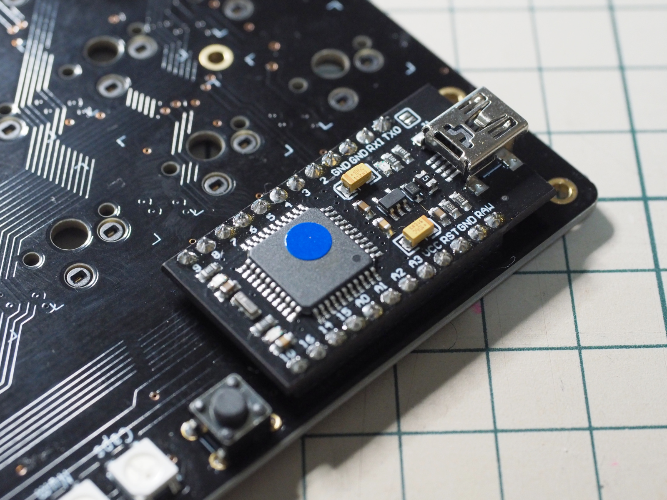
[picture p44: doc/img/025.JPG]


- 間違いなく装着出来たら、写真のようにProMicro側だけコンスルーの足をハンダ付けします。くれぐれもコンスルーのPCB側はハンダ付けしないようにしましょう（※二度と外せなくなります）
- また、この時点でリセットスイッチ用の4ピンタクタイルスイッチもハンダ付けしておきましょう。

<br>

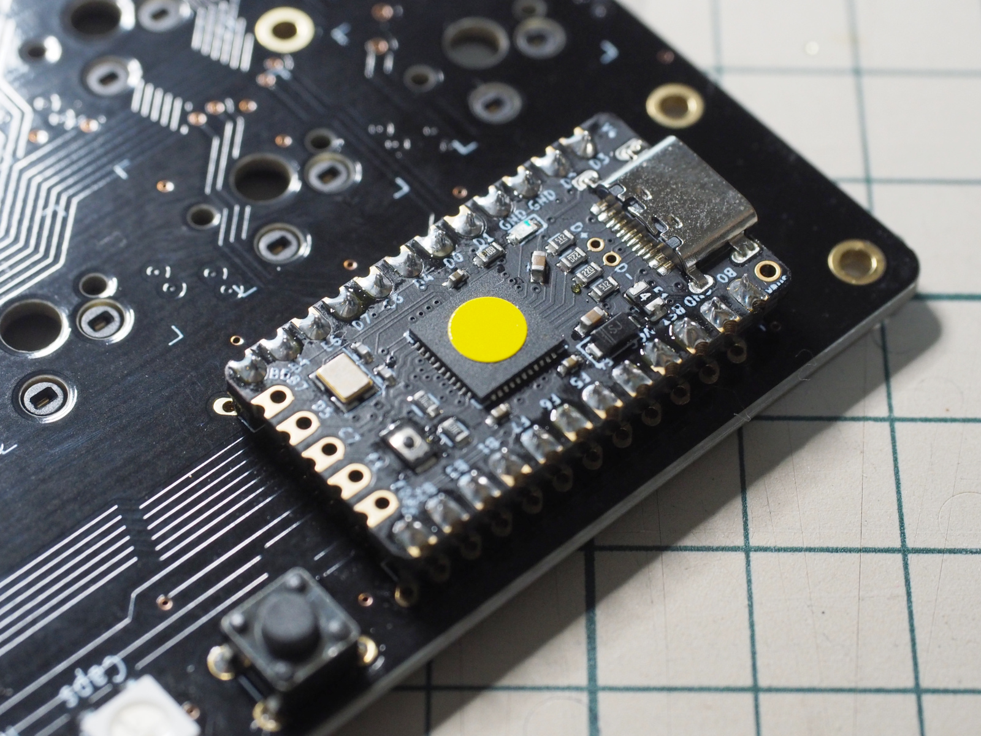
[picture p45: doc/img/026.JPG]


- 参考として600mil幅のProMicro（Elite-C）を装着した場合は、上の写真のように内側の列の穴を使用することになります。

<br>

<br>

## **5：スイッチマウントプレートの取り付け**

<br>

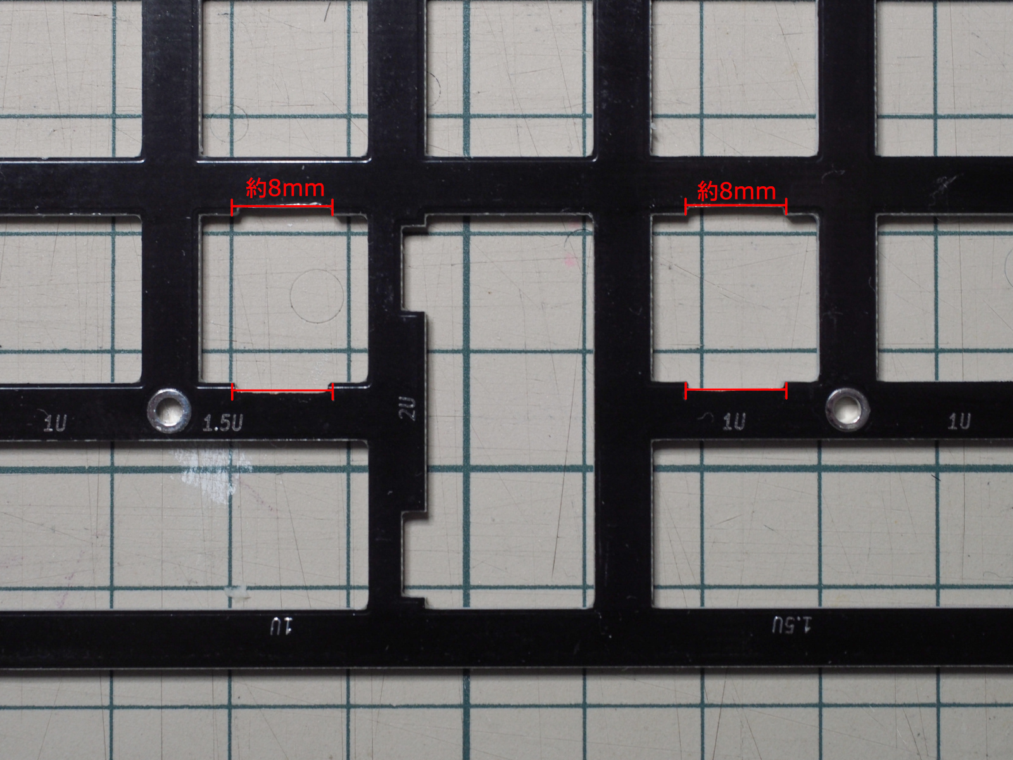
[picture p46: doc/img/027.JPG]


- ロータリーエンコーダを使用する場合は、プレートを装着する前に写真のようにプレートを金属ヤスリで軽く削っておくことをお勧めします。予めこの加工をしておけば、プレートを外すことなくロータリーエンコーダの交換が出来るようになります。

- なお、ロータリーエンコーダを使用せずにMXスイッチのみの構成とする場合は、上記の加工はしない方が良いです（MXスイッチの保持が甘くなってしまうため）

<br>

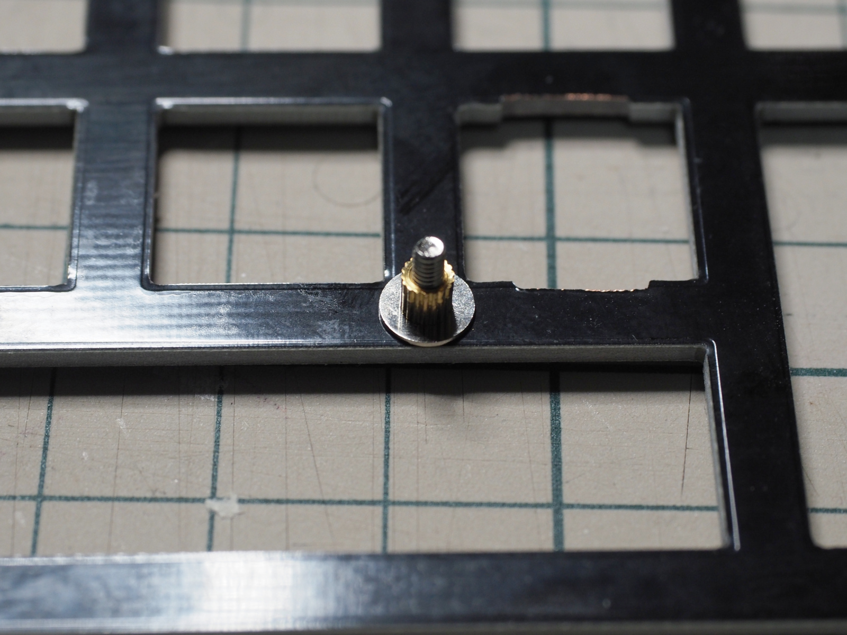
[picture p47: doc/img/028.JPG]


- プレートのネジ穴（8カ所）に写真のようにM2x8mmネジにM2ワッシャーを1枚通してM2x3mmスペーサーで締め付けます。なお、M2ワッシャーはプレート表面とPCB表面のクリアランスを約5mmになるように調整するために挟んでいます。

<br>

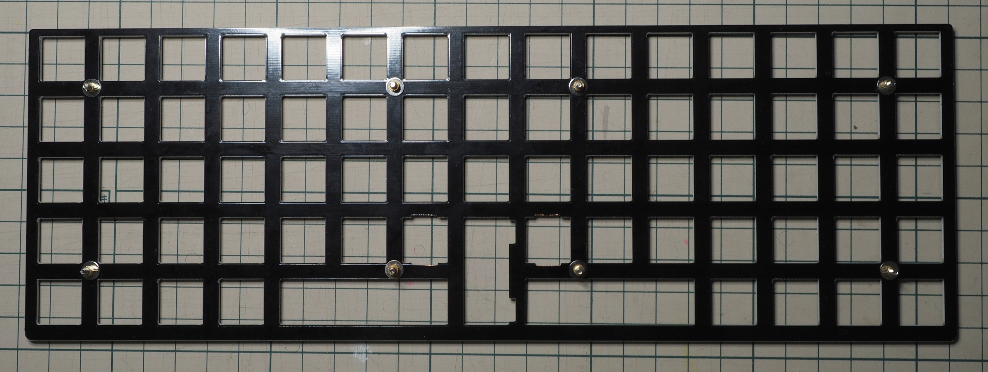
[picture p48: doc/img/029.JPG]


- 8カ所にネジ、ワッシャー、スペーサーを取り付けると上の写真のようになります。

<br>

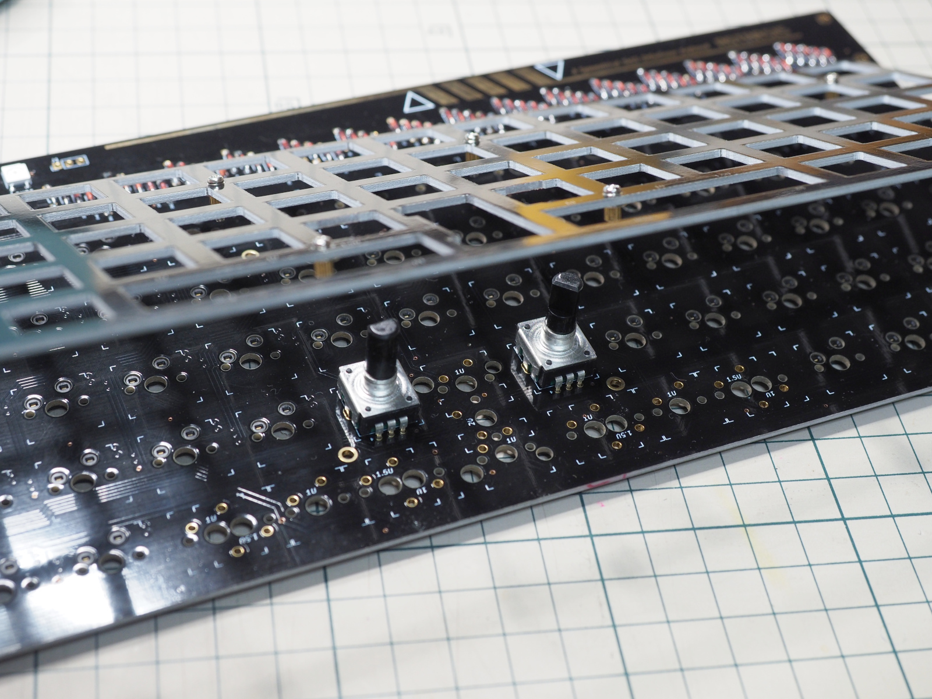
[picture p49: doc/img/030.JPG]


- プレートをPCBに被せます。なお、写真では先にロータリーエンコーダをPCBに差し込んでいますが、上記のプレート切削加工をしている場合は、後から差し込んでも構いません。

- なお、中央下段のキーを縦の2Uサイズとする場合はこの時点で2Uのスタビライザー（別売）をPCBに装着しておく必要があります。

<br>

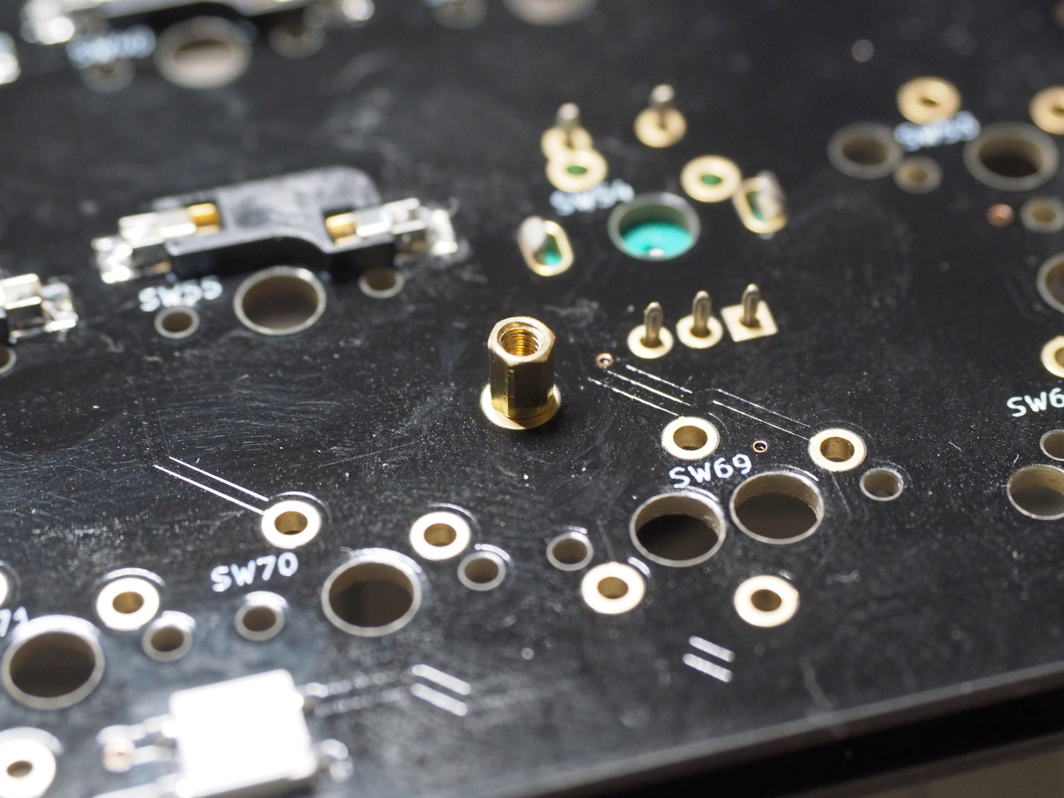
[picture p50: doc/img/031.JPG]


- PCBのネジ穴にプレートのネジが通ったら、PCB裏面からM2x4mmスペーサーで8カ所締めます。手でスペーサー強く締め込んでからプライヤーで掴んで45度程度右に回すと本締めとなります。

<br>

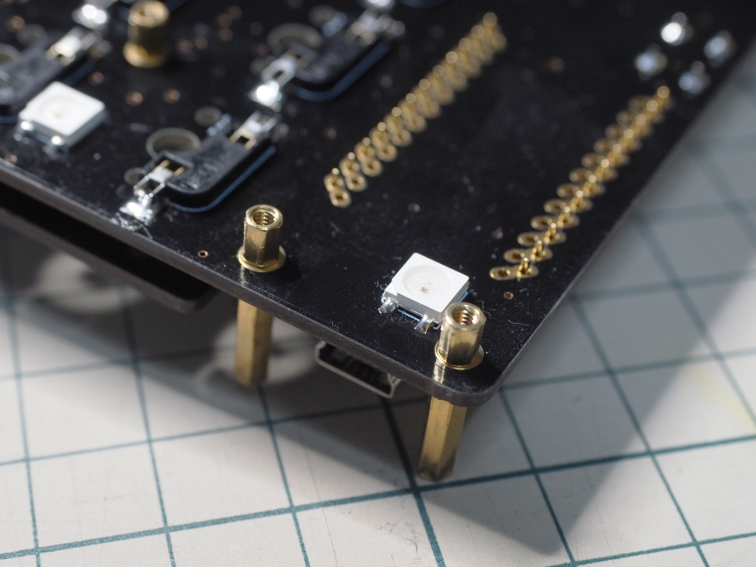
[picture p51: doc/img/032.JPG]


- PCB上部の両端4カ所にM2x12mmスタッドスペーサーをM2x4mmスペーサーで取り付けます。

<br>

<br>

## **6：キースイッチの取り付け**

<br>

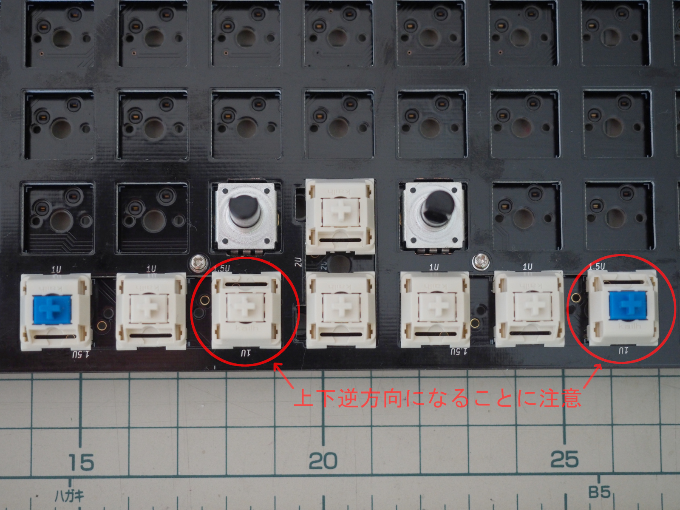
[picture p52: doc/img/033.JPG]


- 上の写真のようにソケット非対応の区画にキースイッチをセットしていきます。なお、キーサイズ選択制の都合により、一部のキースイッチは上下逆方向に取り付けるようになっていますのでご注意ください。

- また、ロータリーエンコーダの代わりにMXスイッチを使用する場合は、3ピンタイプのスイッチでないと入りません。Gateron等の5ピンタイプのスイッチを使う場合はプラスチックの保持ピンをニッパーでカットしてからセットしてください。

- なお、キースイッチの取り付け方向を判別するためにPCBとプレートにキーサイズの表記されています。

<br>

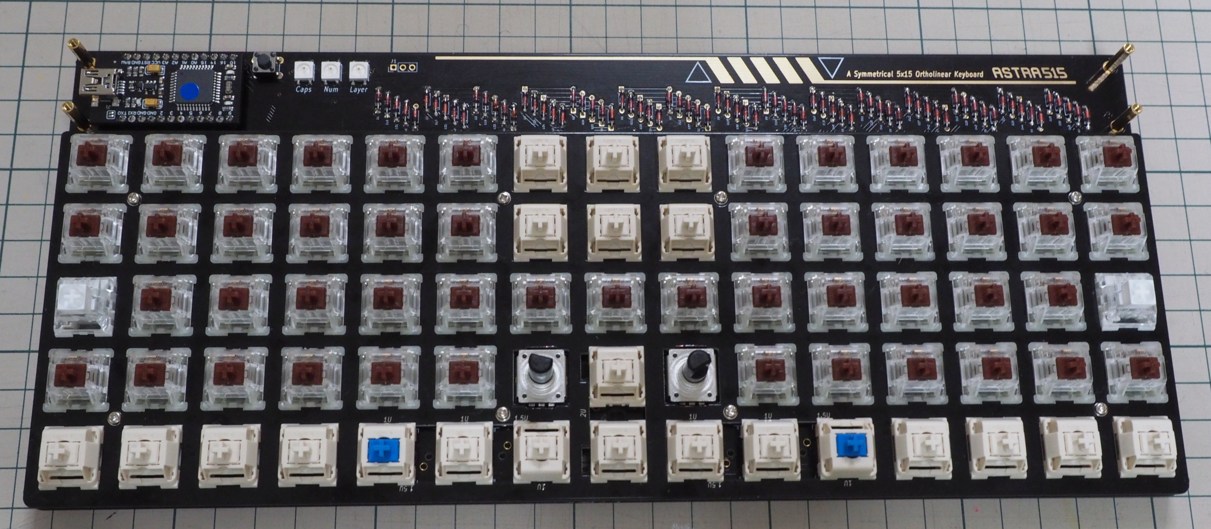
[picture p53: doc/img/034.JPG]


- 続いてソケット対応の区画にキースイッチをセットしていきます。ソケットの場合は無理にスイッチを押し込んで接点のピンが曲がったりしないように注意してください。ハンダ付けと違って失敗しやすい箇所ですのでご注意ください。

- ソケットにスイッチが正しくセットされていることを確認するために、この時点で一旦PCに接続して押したスイッチが反応することを確認しておくと良いでしょう。

<br>

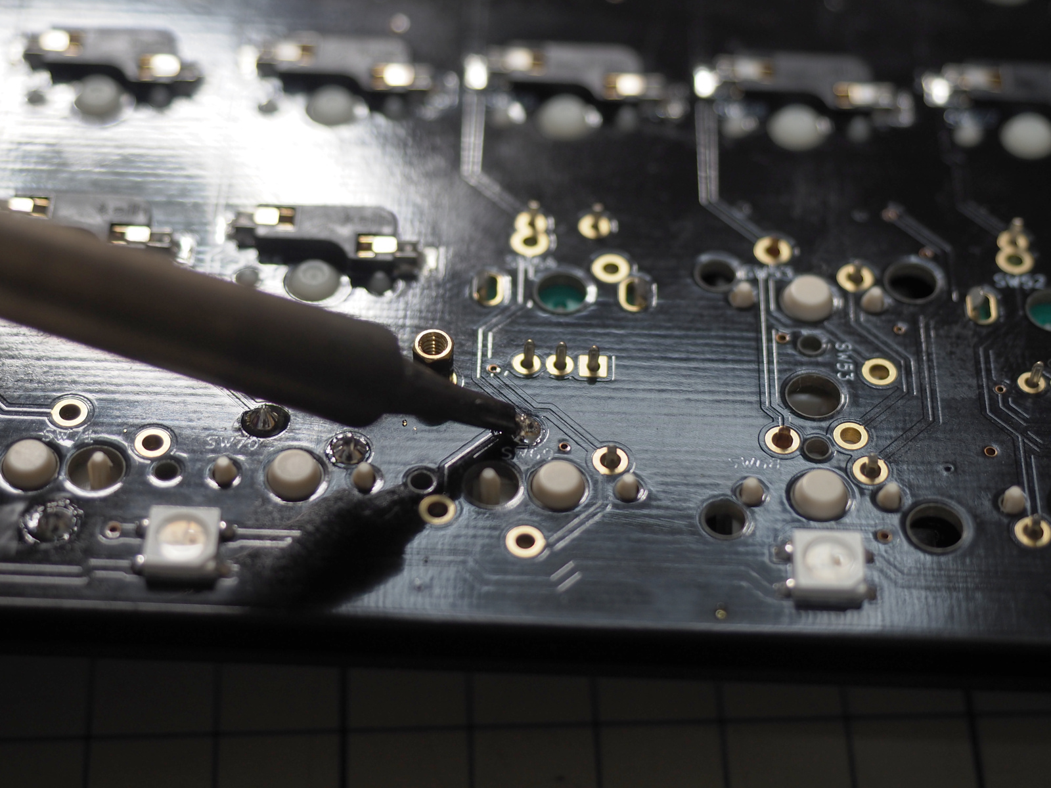
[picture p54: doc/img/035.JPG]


- 基板を裏返して、キースイッチとロータリーエンコーダのハンダ付けをします。なお、ロータリーエンコーダのピンは手前側3カ所と奥側2カ所のピンをハンダ付けすれば十分な強度が得られるので、後で交換する可能性がある場合は左右の保持ピンはハンダ付けしない方が良いと思います。

<br>

<br>

## **7：アクリルプレートの取り付け**

<br>

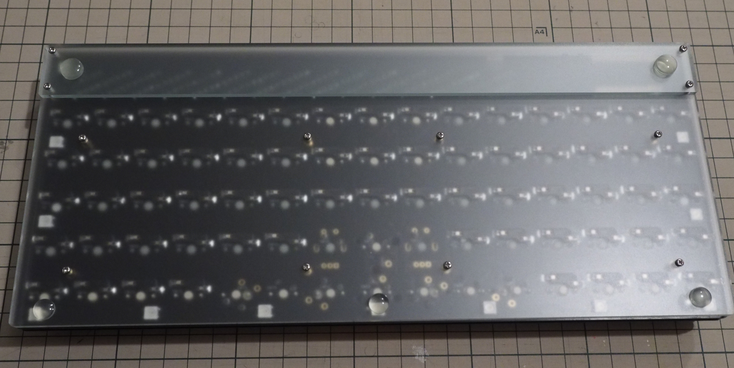
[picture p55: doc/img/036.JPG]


- スイッチ類のハンダ付けが完了したら、写真のようにアクリルのボトムプレートと底上げ用プレートを被せてM2ネジで止めていきます。手前側の8カ所はM2x5mmネジ、奥側両端の4カ所はM2x8mmネジを使用します。

- この時点でゴム足もアクリルプレートに貼付します。手前側にゴム足（小）を、奥側にゴム足（大）を使いますが、奥側は剛性が高く打鍵感が堅くなりやすいので、両端の2カ所だけでいいかも知れません。

（※写真では試作の無刻印ボトムプレートですが、キットには刻印入りのボトムプレートを添付しています）

<br>

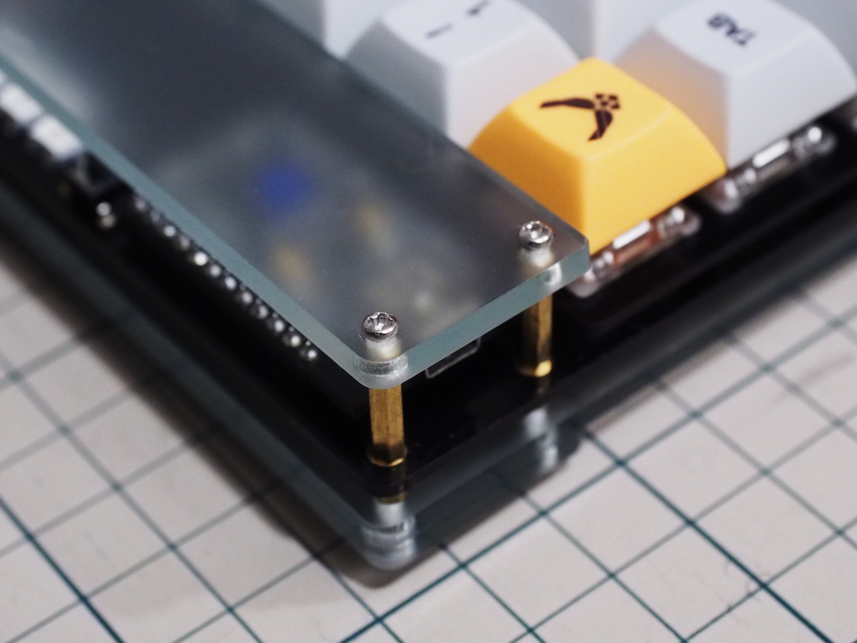
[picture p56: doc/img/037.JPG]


- 最後にキーキャップを取り付けて、トップカバー用のアクリルプレートをM2x5mmネジで取り付けます。

<br>

<br>

<br>

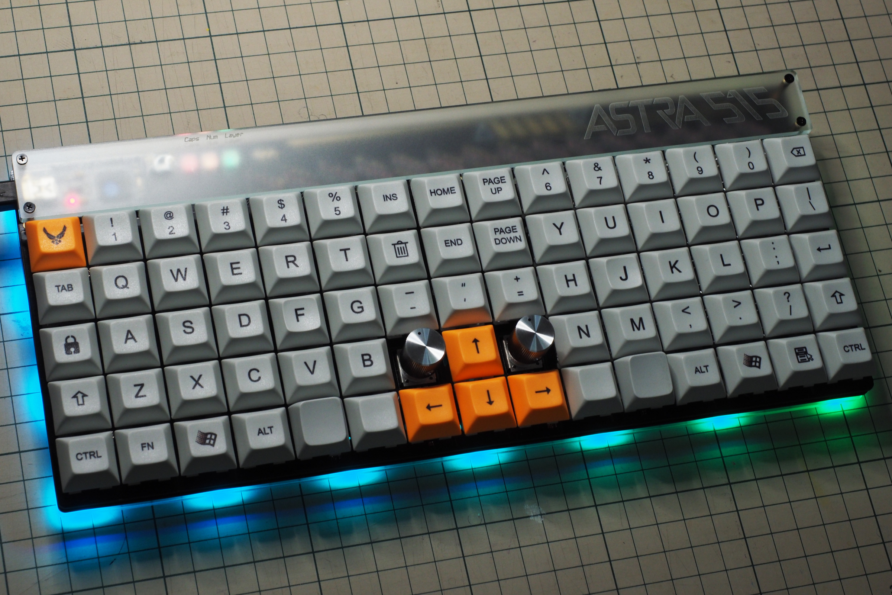
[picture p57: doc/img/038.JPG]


- 以上で組立は終了です。お疲れ様でした。

- ProMicroにはデフォルトキーマップを書き込んでありますので、全てのキーが正しく反応するかチェックしましょう。

<br>

（デフォルトキーマップとQMKファームウェアについては[**別項**](https://github.com/Lekipon/ASTRA515/blob/master/doc/firmware.md)にて記載します）

<br>

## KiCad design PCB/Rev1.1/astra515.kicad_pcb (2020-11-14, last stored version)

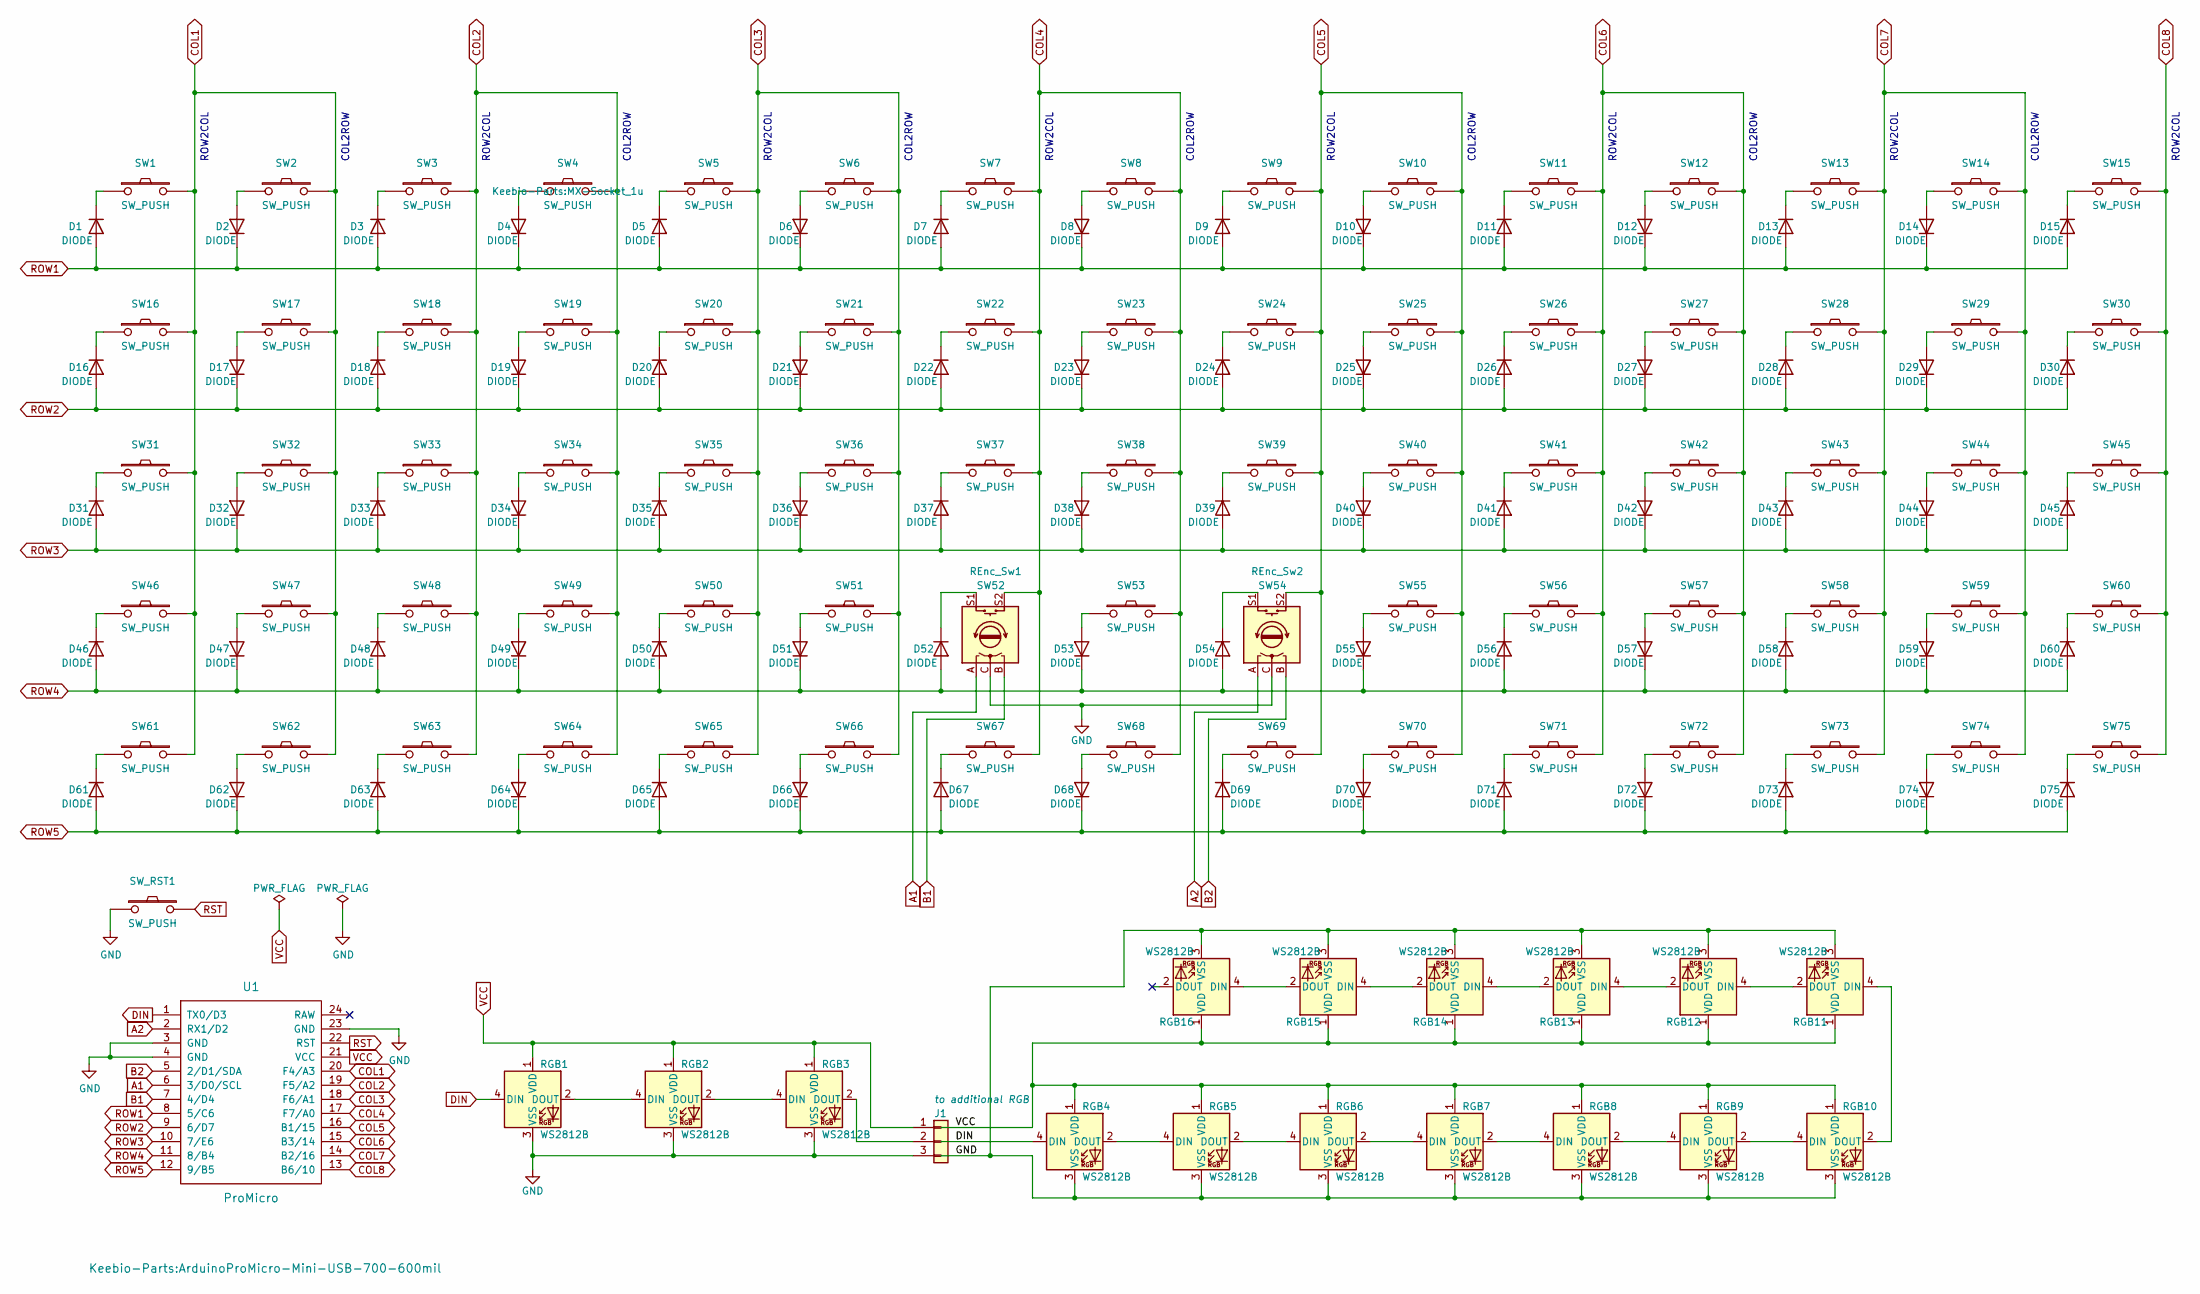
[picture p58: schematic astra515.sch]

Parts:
D1, D2, D3, D4, D5, D6, D7, D8, D9, D10, D11, D12, D13, D14, D15, D16, D17, D18, D19, D20, D21, D22, D23, D24, D25, D26, D27, D28, D29, D30, D31, D32, D33, D34, D35, D36, D37, D38, D39, D40, D41, D42, D43, D44, D45, D46, D47, D48, D49, D50, D51, D52, D53, D54, D55, D56, D57, D58, D59, D60, D61, D62, D63, D64, D65, D66, D67, D68, D69, D70, D71, D72, D73, D74, D75: DIODE; D3_TH_v2_6.35mm
J1: to additional RGB; PinHeader_1x03_P2.54mm_Vertical
RGB1, RGB2, RGB3, RGB4, RGB5, RGB6, RGB7, RGB8, RGB9, RGB10, RGB11, RGB12, RGB13, RGB14, RGB15, RGB16: WS2812B
SW1, SW2, SW3, SW4, SW5, SW6, SW7, SW8, SW9, SW10, SW11, SW12, SW13, SW14, SW15, SW16, SW17, SW18, SW19, SW20, SW21, SW22, SW23, SW24, SW25, SW26, SW27, SW28, SW29, SW30, SW31, SW32, SW33, SW34, SW35, SW36, SW37, SW38, SW39, SW40, SW41, SW42, SW43, SW44, SW45, SW46, SW47, SW48, SW49, SW50, SW51, SW55, SW56, SW57, SW58, SW59, SW60, SW61, SW62, SW63, SW64, SW72, SW73, SW74, SW75: SW_PUSH; MX-Socket_1u
SW52: REnc_Sw1; RotaryEncoder_Alps_EC11E(MX-Switch)
SW53: SW_PUSH; MX_2U-StabFlip
SW54: REnc_Sw2; RotaryEncoder_Alps_EC11E(MX-Switch)
SW65, SW69: SW_PUSH; MX_1U_1.5U(Left)
SW66, SW68, SW70: SW_PUSH; MX_1u
SW67, SW71: SW_PUSH; MX_1U_1.5U(Right)
SW_RST1: SW_PUSH; ResetSW_4P
U1: ProMicro; ArduinoProMicro-Mini-USB-700-600mil

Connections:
A1: SW52.A, U1.6 (3/D0/SCL)
A2: SW54.A, U1.2 (RX1/D2)
B1: SW52.B, U1.7 (4/D4)
B2: SW54.B, U1.5 (2/D1/SDA)
COL1: SW1.2, SW2.2, SW16.2, SW17.2, SW31.2, SW32.2, SW46.2, SW47.2, SW61.2, SW62.2, U1.20 (F4/A3)
COL2: SW3.2, SW4.2, SW18.2, SW19.2, SW33.2, SW34.2, SW48.2, SW49.2, SW63.2, SW64.2, U1.19 (F5/A2)
COL3: SW5.2, SW6.2, SW20.2, SW21.2, SW35.2, SW36.2, SW50.2, SW51.2, SW65.2, SW66.2, U1.18 (F6/A1)
COL4: SW7.2, SW8.2, SW22.2, SW23.2, SW37.2, SW38.2, SW52.S2, SW53.2, SW67.2, SW68.2, U1.17 (F7/A0)
COL5: SW9.2, SW10.2, SW24.2, SW25.2, SW39.2, SW40.2, SW54.S2, SW55.2, SW69.2, SW70.2, U1.16 (B1/15)
COL6: SW11.2, SW12.2, SW26.2, SW27.2, SW41.2, SW42.2, SW56.2, SW57.2, SW71.2, SW72.2, U1.15 (B3/14)
COL7: SW13.2, SW14.2, SW28.2, SW29.2, SW43.2, SW44.2, SW58.2, SW59.2, SW73.2, SW74.2, U1.14 (B2/16)
COL8: SW15.2, SW30.2, SW45.2, SW60.2, SW75.2, U1.13 (B6/10)
DIN: RGB1.4 (DIN), U1.1 (TX0/D3)
GND: J1.3, RGB1.3 (VSS), RGB2.3 (VSS), RGB3.3 (VSS), RGB4.3 (VSS), RGB5.3 (VSS), RGB6.3 (VSS), RGB7.3 (VSS), RGB8.3 (VSS), RGB9.3 (VSS), RGB10.3 (VSS), RGB11.3 (VSS), RGB12.3 (VSS), RGB13.3 (VSS), RGB14.3 (VSS), RGB15.3 (VSS), RGB16.3 (VSS), SW52.C, SW54.C, SW_RST1.1, U1.3 (GND), U1.4 (GND), U1.23 (GND)
unnamed: D1.2 (K), SW1.1
unnamed: D2.1 (A), SW2.1
unnamed: D3.2 (K), SW3.1
unnamed: D4.1 (A), SW4.1
unnamed: D5.2 (K), SW5.1
unnamed: D6.1 (A), SW6.1
unnamed: D7.2 (K), SW7.1
unnamed: D8.1 (A), SW8.1
unnamed: D9.2 (K), SW9.1
unnamed: D10.1 (A), SW10.1
unnamed: D11.2 (K), SW11.1
unnamed: D12.1 (A), SW12.1
unnamed: D13.2 (K), SW13.1
unnamed: D14.1 (A), SW14.1
unnamed: D15.2 (K), SW15.1
unnamed: D16.2 (K), SW16.1
unnamed: D17.1 (A), SW17.1
unnamed: D18.2 (K), SW18.1
unnamed: D19.1 (A), SW19.1
unnamed: D20.2 (K), SW20.1
unnamed: D21.1 (A), SW21.1
unnamed: D22.2 (K), SW22.1
unnamed: D23.1 (A), SW23.1
unnamed: D24.2 (K), SW24.1
unnamed: D25.1 (A), SW25.1
unnamed: D26.2 (K), SW26.1
unnamed: D27.1 (A), SW27.1
unnamed: D28.2 (K), SW28.1
unnamed: D29.1 (A), SW29.1
unnamed: D30.2 (K), SW30.1
unnamed: D31.2 (K), SW31.1
unnamed: D32.1 (A), SW32.1
unnamed: D33.2 (K), SW33.1
unnamed: D34.1 (A), SW34.1
unnamed: D35.2 (K), SW35.1
unnamed: D36.1 (A), SW36.1
unnamed: D37.2 (K), SW37.1
unnamed: D38.1 (A), SW38.1
unnamed: D39.2 (K), SW39.1
unnamed: D40.1 (A), SW40.1
unnamed: D41.2 (K), SW41.1
unnamed: D42.1 (A), SW42.1
unnamed: D43.2 (K), SW43.1
unnamed: D44.1 (A), SW44.1
unnamed: D45.2 (K), SW45.1
unnamed: D46.2 (K), SW46.1
unnamed: D47.1 (A), SW47.1
unnamed: D48.2 (K), SW48.1
unnamed: D49.1 (A), SW49.1
unnamed: D50.2 (K), SW50.1
unnamed: D51.1 (A), SW51.1
unnamed: D52.2 (K), SW52.S1
unnamed: D53.1 (A), SW53.1
unnamed: D54.2 (K), SW54.S1
unnamed: D55.1 (A), SW55.1
unnamed: D56.2 (K), SW56.1
unnamed: D57.1 (A), SW57.1
unnamed: D58.2 (K), SW58.1
unnamed: D59.1 (A), SW59.1
unnamed: D60.2 (K), SW60.1
unnamed: D61.2 (K), SW61.1
unnamed: D62.1 (A), SW62.1
unnamed: D63.2 (K), SW63.1
unnamed: D64.1 (A), SW64.1
unnamed: D65.2 (K), SW65.1
unnamed: D66.1 (A), SW66.1
unnamed: D67.2 (K), SW67.1
unnamed: D68.1 (A), SW68.1
unnamed: D69.2 (K), SW69.1
unnamed: D70.1 (A), SW70.1
unnamed: D71.2 (K), SW71.1
unnamed: D72.1 (A), SW72.1
unnamed: D73.2 (K), SW73.1
unnamed: D74.1 (A), SW74.1
unnamed: D75.2 (K), SW75.1
unnamed: RGB1.2 (DOUT), RGB2.4 (DIN)
unnamed: RGB2.2 (DOUT), RGB3.4 (DIN)
unnamed: RGB4.2 (DOUT), RGB5.4 (DIN)
unnamed: RGB5.2 (DOUT), RGB6.4 (DIN)
unnamed: RGB6.2 (DOUT), RGB7.4 (DIN)
unnamed: RGB7.2 (DOUT), RGB8.4 (DIN)
unnamed: RGB8.2 (DOUT), RGB9.4 (DIN)
unnamed: RGB10.2 (DOUT), RGB11.4 (DIN)
unnamed: RGB9.2 (DOUT), RGB10.4 (DIN)
unnamed: RGB11.2 (DOUT), RGB12.4 (DIN)
unnamed: RGB12.2 (DOUT), RGB13.4 (DIN)
unnamed: RGB13.2 (DOUT), RGB14.4 (DIN)
unnamed: RGB14.2 (DOUT), RGB15.4 (DIN)
unnamed: RGB15.2 (DOUT), RGB16.4 (DIN)
ROW1: D1.1 (A), D2.2 (K), D3.1 (A), D4.2 (K), D5.1 (A), D6.2 (K), D7.1 (A), D8.2 (K), D9.1 (A), D10.2 (K), D11.1 (A), D12.2 (K), D13.1 (A), D14.2 (K), D15.1 (A), U1.8 (5/C6)
ROW2: D16.1 (A), D17.2 (K), D18.1 (A), D19.2 (K), D20.1 (A), D21.2 (K), D22.1 (A), D23.2 (K), D24.1 (A), D25.2 (K), D26.1 (A), D27.2 (K), D28.1 (A), D29.2 (K), D30.1 (A), U1.9 (6/D7)
ROW3: D31.1 (A), D32.2 (K), D33.1 (A), D34.2 (K), D35.1 (A), D36.2 (K), D37.1 (A), D38.2 (K), D39.1 (A), D40.2 (K), D41.1 (A), D42.2 (K), D43.1 (A), D44.2 (K), D45.1 (A), U1.10 (7/E6)
ROW4: D46.1 (A), D47.2 (K), D48.1 (A), D49.2 (K), D50.1 (A), D51.2 (K), D52.1 (A), D53.2 (K), D54.1 (A), D55.2 (K), D56.1 (A), D57.2 (K), D58.1 (A), D59.2 (K), D60.1 (A), U1.11 (8/B4)
ROW5: D61.1 (A), D62.2 (K), D63.1 (A), D64.2 (K), D65.1 (A), D66.2 (K), D67.1 (A), D68.2 (K), D69.1 (A), D70.2 (K), D71.1 (A), D72.2 (K), D73.1 (A), D74.2 (K), D75.1 (A), U1.12 (9/B5)
RST: SW_RST1.2, U1.22 (RST)
VCC: J1.1, RGB1.1 (VDD), RGB2.1 (VDD), RGB3.1 (VDD), RGB4.1 (VDD), RGB5.1 (VDD), RGB6.1 (VDD), RGB7.1 (VDD), RGB8.1 (VDD), RGB9.1 (VDD), RGB10.1 (VDD), RGB11.1 (VDD), RGB12.1 (VDD), RGB13.1 (VDD), RGB14.1 (VDD), RGB15.1 (VDD), RGB16.1 (VDD), U1.21 (VCC)

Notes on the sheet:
ROW2COL
COL2ROW

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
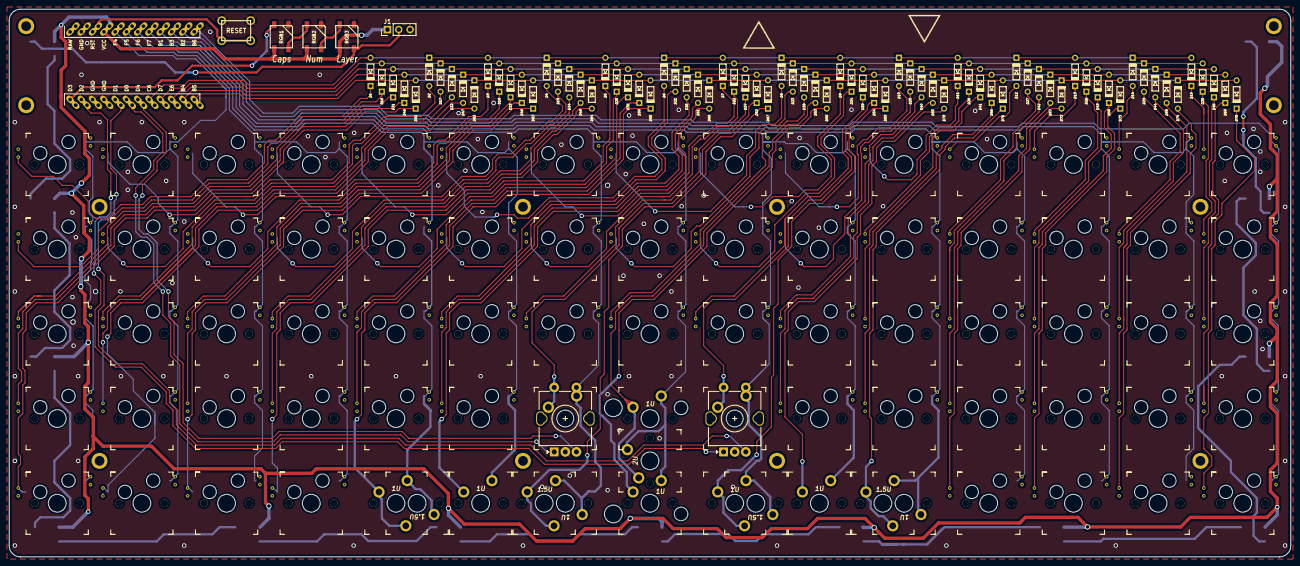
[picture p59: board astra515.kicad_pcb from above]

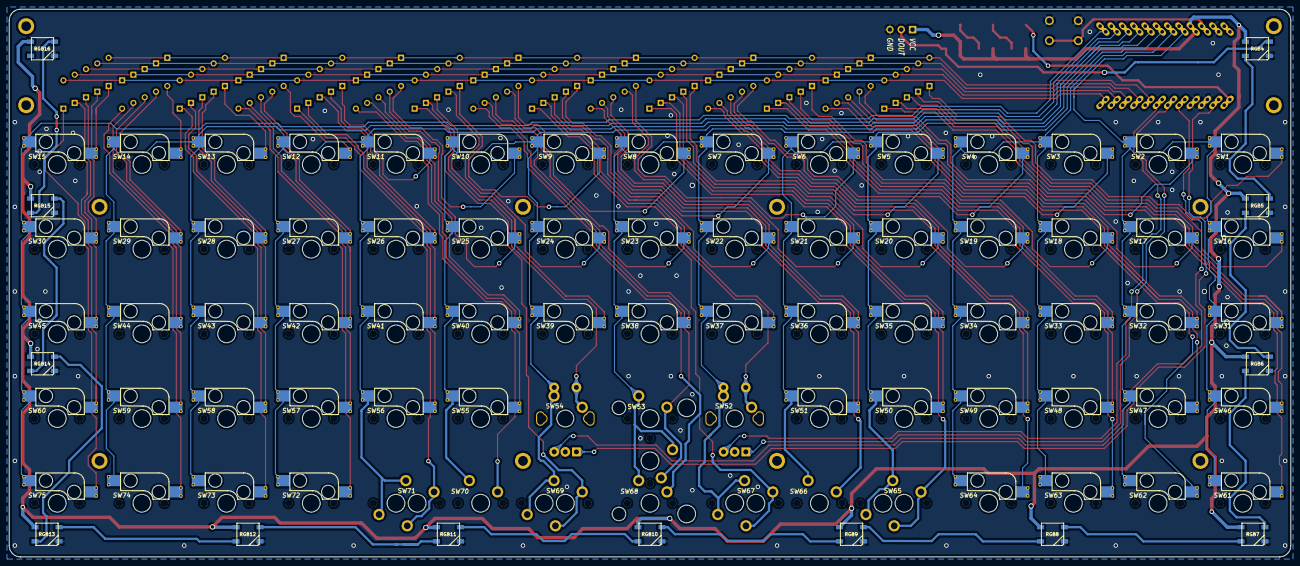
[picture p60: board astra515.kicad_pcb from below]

Board: 2 copper layers, 288.3 x 123.2 mm, 181 parts (13 on the bottom side), 111 nets.

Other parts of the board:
Ref**: Val**; M2_HOLE_3.6
Ref**#2, Ref**#3, Ref**#4, Ref**#5, Ref**#6, Ref**#7, Ref**#8, Ref**#9, Ref**#10, Ref**#11, Ref**#12: Val**; M2_HOLE_3.6

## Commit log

2020-11-14 Add PCB Data
    [astra515.kicad_pcb, astra515.sch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]
2020-11-15 Removed kicad data
    [astra515.kicad_pcb, astra515.sch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]
